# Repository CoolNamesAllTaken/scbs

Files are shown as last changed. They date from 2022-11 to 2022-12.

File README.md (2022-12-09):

# scbs
Single Cell Battery Simulator for testing a BMS.

# CELLSIM 4S

Cellsim 4S is a low-current battery pack simulator that simulates four battery cells in series. Each cell has a settable output voltage between 2.5-4.5V and a readable output current. Communication is done over a 9600 baud UART link using a custom serial protocol.

[DATASHEET](word/datasheet_cellsim_4s-1.0.0.pdf)

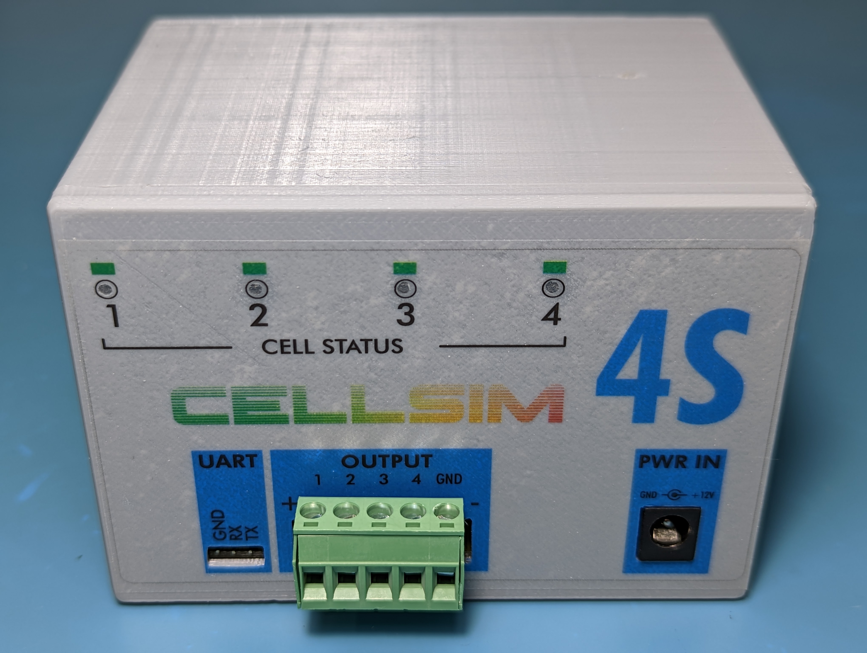
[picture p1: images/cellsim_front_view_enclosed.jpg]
Cellsim 4S Front View


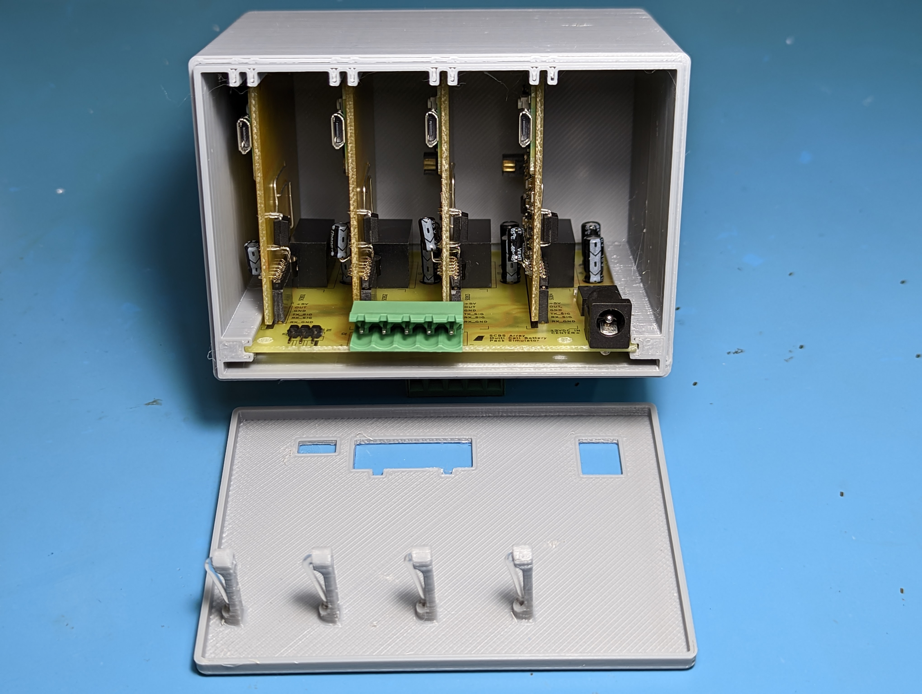
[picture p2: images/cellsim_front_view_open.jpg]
Cellsim 4S Internal View


# SCBS Pico

SCBS Pico is a single battery cell simulator that can be daisy chained with other devices of the same type in order to build a full simulated battery pack. It is the basic building block of the CELLSIM 4S.

[DATASHEET](word/datasheet_scbs_pico.pdf)

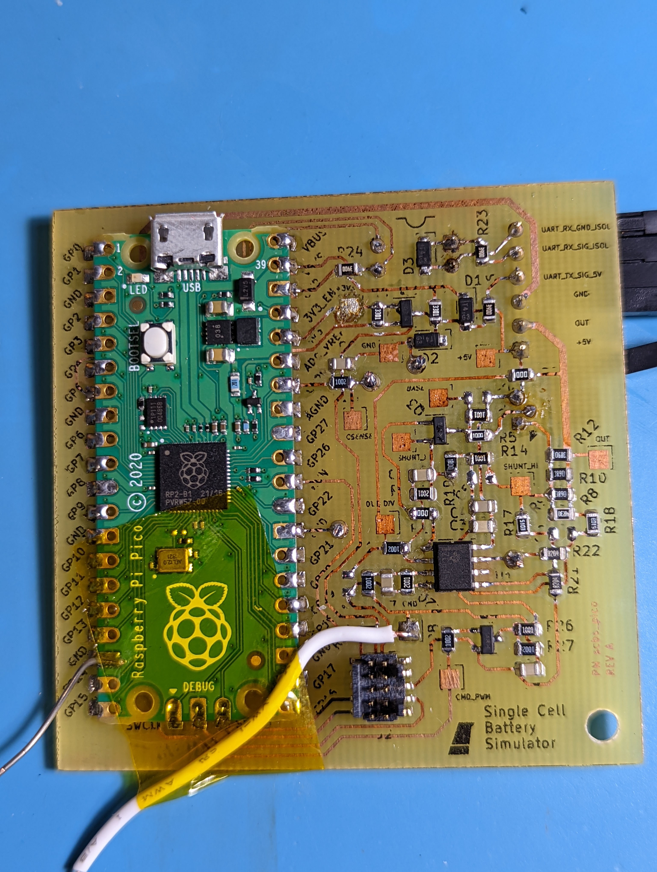
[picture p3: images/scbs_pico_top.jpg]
SCBS Pico Top


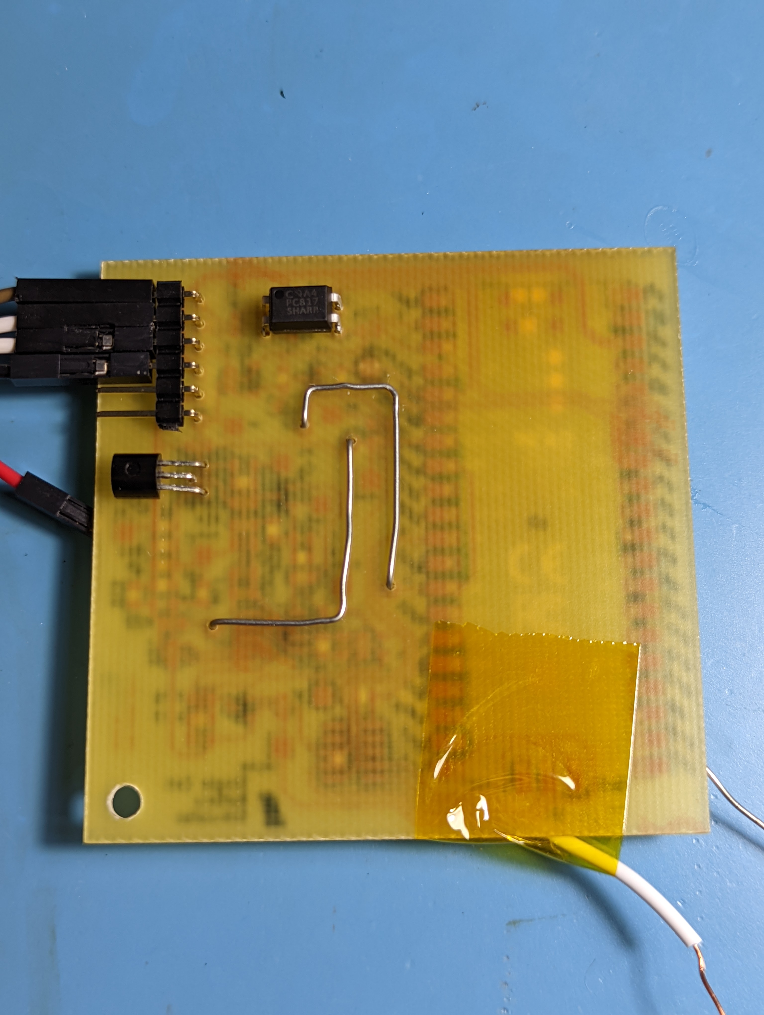
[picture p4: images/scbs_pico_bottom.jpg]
SCBS Pico Bottom


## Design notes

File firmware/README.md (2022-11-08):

# scbs

## Docker Setup Instructions

Run these commands from the top level directory.

NOTE: Cloning git repos onto windows may result in files with CR+LF line endings. Docker does NOT like these, and they will break everything. Make sure that you set `git config --global core.autocrlf false` before cloning repos that will get added or mounted to a Docker container.

### Build the Docker Image

Be sure to run `git submodule update --init` before building!

From this directory, run the following shell command.

```bash
docker build -t pico-dev-image .
```

### Run the Docker Container

Starting an interactive docker container on Linux or Mac. Mounts the `firmware` directory to `/root/firmware`.

```bash
docker run --name scbs-pico-dev-container -it --mount type=bind,source="$(pwd)",target=/root/scbs pico-dev-image
```

Starting an interactive docker container on Windows. Mounts the `firmware` directory to `/root/firmware`.

```bash
winpty docker run --name scbs-pico-dev-container -it --mount type=bind,source="$(pwd)",target=/root/scbs pico-dev-image
```

### Remove the Docker Image

```bash
docker image rm pico-dev-image
```

## Using VS Code inside the Docker Container

1. Install the Docker VS Code extension.
2. Right click on the available pico-dev-container and select "Attach Visual Studio Code" from the dropdown menu.
3. Open the attached VS Code, and wait for it to finish installing docker stuff.
4. In the attached visual studio code, install Cortex-Debug and the C/C++ extension.
5. To debug using the `launch.json` file in the `firmware/.vscode` directory, use the "Open Folder" function to navigate the attached VS Code instance to the `firmware` directory.

## Building Tests

### Build GoogleTest
In the docker container, navigate to the `modules/googletest` folder and execute the following.

```bash
cd googletest        # Main directory of the cloned repository.
mkdir build          # Create a directory to hold the build output.
cd build
cmake -DBUILD_SHARED_LIBS=ON .. # Generate build scripts with .so files.
make
```

This will generate the libgtest.so file that is a dependency of the SCBS tests in the next section.

### Build SCBS Tests
Create a folder called `test/build` and open a terminal there.
```bash
cmake ..
make
./scbs_test
```

## Initializing Submodules

From the `modules` directory, run `git submodule update --init --recursive`.

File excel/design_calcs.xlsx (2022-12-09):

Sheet: Design Calculations
Symbol | Value | Units | Note
Non-Inverting Amplifier Calculations (Control Circuit)
V_dac_max | 3.3 | V
V_batt_max | 4.7 | V | Add 0.2V of headroom to be safe.
R_fb | 10 | kOhms | Bottom feedback resistor (to GND) on opamp inverting input.
A_v_amp | 1.424242424
R_ft | 14.24142424 | kOhms
Compensation Network
R_comp | 10 | kOhms
C_comp | 10 | uF
f_c_comp | 1591.549431 | kHz | Corner frequency of filter on output of control op-amp.
PWM Smoothing Filter
R_fillt | 10000 | kOhms
C_filt | 10 | uF
f_c_filt | 1.591549431 | kHz
V_be_2n3904 | 0.7 | V
V_pwm_max | 3.3 | V
R_b_pwm | 10 | kOhms
I_b_pwm | 2.6
Current Sense Calculations
R_shunt | 0.9982142857 | Ohm
I_shunt_max | 200 | mA
V_shunt_max | 0.1996428571
V_sense_max | 3.3 | V
A_v | 16.52951699 | V_sense / V_shunt
Blob_A | 0.9429533626 | R_ub / (R_ub + R_ut)
R_ut | 510 | kOhms
R_ub | 8430.053667 | kOhms
R_db | 8430.053667 | kOhms
R_dt | 510 | kOhms

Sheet: Output Voltage Calibration
Set Voltage | Output Voltage | Offset |  | Estimated Offset
0 | 0.099 | 0.099 |  | 0.07958601399
0.5 | 0.423 | -0.077 |  | -0.04233473193
1 | 0.865 | -0.135 |  | -0.1331307692
1.5 | 1.314 | -0.186 |  | -0.1977706294
2 | 1.771 | -0.229 |  | -0.2412228438
2.5 | 2.237 | -0.263 |  | -0.2684559441
3 | 2.712 | -0.288 |  | -0.2844384615
3.5 | 3.196 | -0.304 |  | -0.2941389277
4 | 3.69 | -0.31 |  | -0.3025258741
4.5 | 4.194 | -0.306 |  | -0.3145678322
 |  |  | Offset Polynomial | COEFF_X^3 | COEFF_X^2 | COEFF_X | COEFF_CONST
 |  |  |  | -0.006624708625 | 0.07218648019 | -0.2782785548 | 0.07958601399

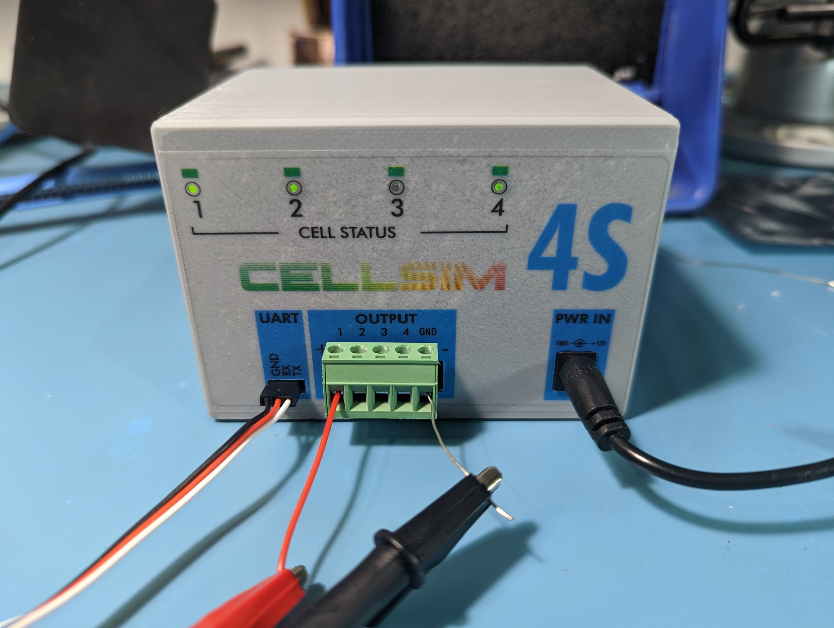
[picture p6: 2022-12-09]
images/cellsim_connected.jpg

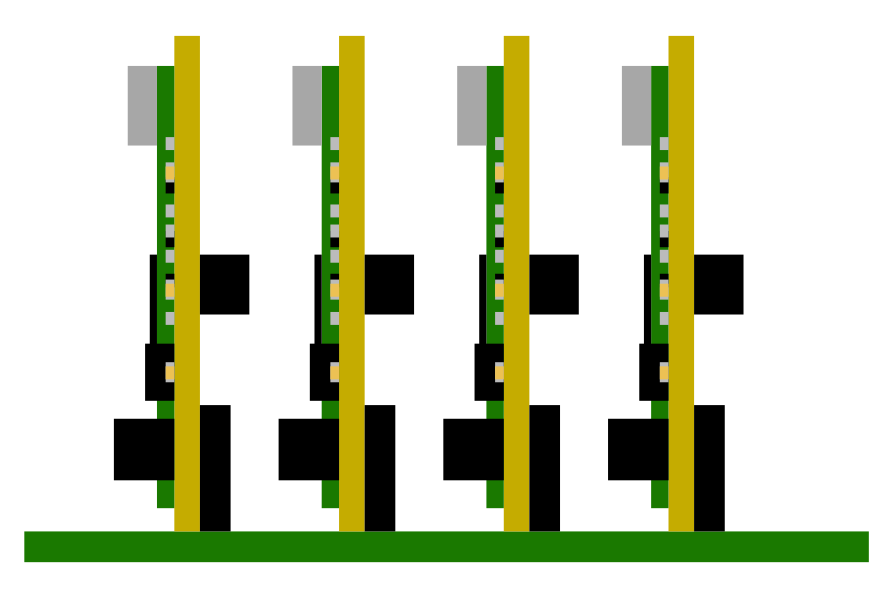
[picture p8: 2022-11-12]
affinity/exports/scbs_array.png

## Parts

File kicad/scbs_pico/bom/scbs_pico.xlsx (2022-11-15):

Source: | C:\git-checkouts\scbs\kicad\scbs_demo\scbs_demo.kicad_sch
Date: | 2022-11-10 20:58
Tool: | Eeschema (6.0.7)
Generator: | C:\Program Files\KiCad\6.0\bin\scripting\plugins/bom_csv_grouped_by_value.py
Component Count: | 62
Individual Components:
Item | Qty | Reference(s) | Value | LibPart | Footprint | Datasheet | MPN | REV | Standard Cost
 |  | C1 | 0.1uF | Device:C | Capacitor_SMD:C_0805_2012Metric | ~ |  |  | 0.1
 |  | C2 | DNP | Device:C | Capacitor_SMD:C_0805_2012Metric | ~ |  |  | 0.1
 |  | C3 | 1uF | Device:C | Capacitor_SMD:C_0805_2012Metric | ~ |  |  | 0.1
 |  | C4 | 0.1uF | Device:C | Capacitor_SMD:C_0805_2012Metric | ~ |  |  | 0.1
 |  | C5 | DNP | Device:C | Capacitor_SMD:C_0805_2012Metric | ~ |  |  | 0.1
 |  | C6 | DNP | Device:C | Capacitor_SMD:C_0805_2012Metric | ~ |  |  | 0.1
 |  | C7 | 0.1uF | Device:C | Capacitor_SMD:C_0805_2012Metric | ~ |  |  | 0.1
 |  | C8 | 0.1uF | Device:C | Capacitor_SMD:C_0805_2012Metric | ~ |  |  | 0.1
 |  | C9 | 0.1uF | Device:C | Capacitor_SMD:C_0805_2012Metric | ~ |  |  | 0.1
 |  | D1 | 1N4148 | Device:D | Diode_SMD:D_SOD-123 | ~ | 1N4148W-TP |  | 0.04
 |  | D2 | 1N4148 | Device:D | Diode_SMD:D_SOD-123 | ~ | 1N4148W-TP |  | 0.04
 |  | D3 | 1N4148 | Device:D | Diode_SMD:D_SOD-123 | ~ | 1N4148W-TP |  | 0.04
 |  | J1 | Conn_01x06_Male | Connector:Conn_01x06_Male | Connector_PinHeader_2.54mm:PinHeader_1x06_P2.54mm_Horizontal | ~ | PREC006SBAN-M71RC |  | 0.1
 |  | J2 | Conn_ARM_JTAG_SWD_10 | Connector:Conn_ARM_JTAG_SWD_10 | Connector_PinHeader_1.27mm:PinHeader_2x05_P1.27mm_Vertical_SMD | http://infocenter.arm.com/help/topic/com.arm.doc.ddi0314h/DDI0314H_coresight_components_trm.pdf | 4048 |  | 1.95
 |  | PCB1 | PCB | Custom_Placeholder:PCB | Custom_Graphic:PCB_PN_REV_small |  | PN scbs_pico | REV A | 0
 |  | Q1 | 2N2907 | Device:Q_PNP_CBE | Package_TO_SOT_THT:TO-92 | https://www.onsemi.com/pdf/datasheet/p2n2907a-d.pdf | PN2907ATF |  | 0.07
 |  | Q2 | 2N7002 | Transistor_FET:2N7002 | Package_TO_SOT_SMD:SOT-23 | https://www.onsemi.com/pub/Collateral/NDS7002A-D.PDF | 2N7002 |  | 0.07
 |  | Q3 | MMBT3904 | Transistor_BJT:MMBT3904 | Package_TO_SOT_SMD:SOT-23 | https://www.onsemi.com/pub/Collateral/2N3903-D.PDF |  |  | 0.04
 |  | Q4 | MMBT3904 | Transistor_BJT:MMBT3904 | Package_TO_SOT_SMD:SOT-23 | https://www.onsemi.com/pub/Collateral/2N3903-D.PDF |  |  | 0.04
 |  | R1 | 2k | Device:R_US | Resistor_SMD:R_0805_2012Metric | ~ |  |  | 0.01
 |  | R2 | 1k | Device:R_US | Resistor_SMD:R_0805_2012Metric | ~ |  |  | 0.01
 |  | R3 | 3k3 | Device:R_US | Resistor_SMD:R_0805_2012Metric | ~ |  |  | 0.01
 |  | R4 | 3k3 | Device:R_US | Resistor_SMD:R_0805_2012Metric | ~ |  |  | 0.01
 |  | R5 | 100R | Device:R_US | Resistor_SMD:R_0805_2012Metric | ~ |  |  | 0.01
 |  | R6 | 390R | Device:R_US | Resistor_SMD:R_0805_2012Metric | ~ |  |  | 0.01
 |  | R7 | 0R | Device:R_US | Resistor_SMD:R_0805_2012Metric | ~ |  |  | 0.01
 |  | R8 | 4R 1% 0805 | Device:R_US | Resistor_SMD:R_0805_2012Metric | ~ |  |  | 0.01
 |  | R9 | 4R 1% 0805 | Device:R_US | Resistor_SMD:R_0805_2012Metric | ~ |  |  | 0.01
 |  | R10 | 4R 1% 0805 | Device:R_US | Resistor_SMD:R_0805_2012Metric | ~ |  |  | 0.01
 |  | R11 | 10k | Device:R_US | Resistor_SMD:R_0805_2012Metric | ~ |  |  | 0.01
 |  | R12 | 4R 1% 0805 | Device:R_US | Resistor_SMD:R_0805_2012Metric | ~ |  |  | 0.01
 |  | R13 | 0R | Device:R_US | Resistor_SMD:R_0805_2012Metric | ~ |  |  | 0.01
 |  | R14 | 1k | Device:R_US | Resistor_SMD:R_0805_2012Metric | ~ |  |  | 0.01
 |  | R15 | 10k | Device:R_US | Resistor_SMD:R_0805_2012Metric | ~ |  |  | 0.01
 |  | R16 | DNP | Device:R_US | Resistor_SMD:R_0805_2012Metric | ~ |  |  | 0.01
 |  | R17 | 500k 0.1% | Device:R_US | Resistor_SMD:R_0805_2012Metric | ~ |  |  | 0.01
 |  | R18 | 500k 0.1% | Device:R_US | Resistor_SMD:R_0805_2012Metric | ~ |  |  | 0.01
 |  | R19 | 1R | Device:R_US | Resistor_SMD:R_0805_2012Metric | ~ |  |  | 0.01
 |  | R20 | 2k | Device:R_US | Resistor_SMD:R_0805_2012Metric | ~ |  |  | 0.01
 |  | R21 | 8.25M 0.1% | Device:R_US | Resistor_SMD:R_0805_2012Metric | ~ |  |  | 0.01
 |  | R22 | 8.25M 0.1% | Device:R_US | Resistor_SMD:R_0805_2012Metric | ~ |  |  | 0.01
 |  | R23 | 390R | Device:R_US | Resistor_SMD:R_0805_2012Metric | ~ |  |  | 0.01
 |  | R24 | 390R | Device:R_US | Resistor_SMD:R_0805_2012Metric | ~ |  |  | 0.01
 |  | R25 | 10k | Device:R_US | Resistor_SMD:R_0805_2012Metric | ~ |  |  | 0.01
 |  | R26 | 1k | Device:R_US | Resistor_SMD:R_0805_2012Metric | ~ |  |  | 0.01
 |  | R27 | 10k | Device:R_US | Resistor_SMD:R_0805_2012Metric | ~ |  |  | 0.01
 |  | R28 | 10k | Device:R_US | Resistor_SMD:R_0805_2012Metric | ~ |  |  | 0.01
 |  | R30 | 10k | Device:R_US | Resistor_SMD:R_0805_2012Metric | ~ |  |  | 0.01
 |  | TP1 | TestPoint | Connector:TestPoint | TestPoint:TestPoint_Pad_2.0x2.0mm | ~ |  |  | 0
 |  | TP2 | TestPoint | Connector:TestPoint | TestPoint:TestPoint_Pad_2.0x2.0mm | ~ |  |  | 0
 |  | TP3 | TestPoint | Connector:TestPoint | TestPoint:TestPoint_Pad_2.0x2.0mm | ~ |  |  | 0
 |  | TP4 | TestPoint | Connector:TestPoint | TestPoint:TestPoint_Pad_2.0x2.0mm | ~ |  |  | 0
 |  | TP5 | TestPoint | Connector:TestPoint | TestPoint:TestPoint_Pad_2.0x2.0mm | ~ |  |  | 0
 |  | TP6 | TestPoint | Connector:TestPoint | TestPoint:TestPoint_Pad_2.0x2.0mm | ~ |  |  | 0
 |  | TP7 | TestPoint | Connector:TestPoint | TestPoint:TestPoint_Pad_2.0x2.0mm | ~ |  |  | 0
 |  | TP8 | TestPoint | Connector:TestPoint | TestPoint:TestPoint_Pad_2.0x2.0mm | ~ |  |  | 0
 |  | TP9 | TestPoint | Connector:TestPoint | TestPoint:TestPoint_Pad_2.0x2.0mm | ~ |  |  | 0
 |  | TP10 | TestPoint | Connector:TestPoint | TestPoint:TestPoint_Pad_2.0x2.0mm | ~ |  |  | 0
 |  | TP11 | TestPoint | Connector:TestPoint | TestPoint:TestPoint_Pad_2.0x2.0mm | ~ |  |  | 0
 |  | U1 | TLV9062xD | Amplifier_Operational:TLV9062xD | Package_SO:SOIC-8_3.9x4.9mm_P1.27mm | https://www.ti.com/lit/ds/symlink/tlv9062.pdf | TLV9062IDR |  | 0.44
 |  | U2 | PC817 | Isolator:PC817 | Package_DIP:DIP-4_W7.62mm | http://www.soselectronic.cz/a_info/resource/d/pc817.pdf | BPC-817S ( C BIN ) |  | 0.15
 |  | U3 | Pico | Custom_MCU:Pico | Custom_Module:RPi_Pico_SMD_TH | https://datasheets.raspberrypi.com/pico/pico-datasheet.pdf | SC0915 |  | 4
Collated Components:
Item | Qty | Reference(s) | Value | LibPart | Footprint | Datasheet | MPN | REV | Standard Cost | Subtotal
1 | 5 | C1, C4, C7, C8, C9 | 0.1uF | Device:C | Capacitor_SMD:C_0805_2012Metric | ~ |  |  | 0.1 | 0.5
2 | 3 | C2, C5, C6 | DNP | Device:C | Capacitor_SMD:C_0805_2012Metric | ~ |  |  | 0.1 | 0.3
3 | 1 | C3 | 1uF | Device:C | Capacitor_SMD:C_0805_2012Metric | ~ |  |  | 0.1 | 0.1
4 | 3 | D1, D2, D3 | 1N4148 | Device:D | Diode_SMD:D_SOD-123 | ~ | 1N4148W-TP |  | 0.04 | 0.12
5 | 1 | J1 | Conn_01x06_Male | Connector:Conn_01x06_Male | Connector_PinHeader_2.54mm:PinHeader_1x06_P2.54mm_Horizontal | ~ | PREC006SBAN-M71RC |  | 0.1 | 0.1
6 | 1 | J2 | Conn_ARM_JTAG_SWD_10 | Connector:Conn_ARM_JTAG_SWD_10 | Connector_PinHeader_1.27mm:PinHeader_2x05_P1.27mm_Vertical_SMD | http://infocenter.arm.com/help/topic/com.arm.doc.ddi0314h/DDI0314H_coresight_components_trm.pdf | 4048 |  | 1.95 | 1.95
7 | 1 | PCB1 | PCB | Custom_Placeholder:PCB | Custom_Graphic:PCB_PN_REV_small |  | PN scbs_pico | REV A | 0 | 0
8 | 1 | Q1 | 2N2907 | Device:Q_PNP_CBE | Package_TO_SOT_THT:TO-92 | https://www.onsemi.com/pdf/datasheet/p2n2907a-d.pdf | PN2907ATF |  | 0.07 | 0.07
9 | 1 | Q2 | 2N7002 | Transistor_FET:2N7002 | Package_TO_SOT_SMD:SOT-23 | https://www.onsemi.com/pub/Collateral/NDS7002A-D.PDF | 2N7002 |  | 0.07 | 0.07
10 | 2 | Q3, Q4 | MMBT3904 | Transistor_BJT:MMBT3904 | Package_TO_SOT_SMD:SOT-23 | https://www.onsemi.com/pub/Collateral/2N3903-D.PDF |  |  | 0.04 | 0.08
11 | 2 | R1, R20 | 2k | Device:R_US | Resistor_SMD:R_0805_2012Metric | ~ |  |  | 0.01 | 0.02
12 | 3 | R2, R14, R26 | 1k | Device:R_US | Resistor_SMD:R_0805_2012Metric | ~ |  |  | 0.01 | 0.03
13 | 2 | R3, R4 | 3k3 | Device:R_US | Resistor_SMD:R_0805_2012Metric | ~ |  |  | 0.01 | 0.02
14 | 1 | R5 | 100R | Device:R_US | Resistor_SMD:R_0805_2012Metric | ~ |  |  | 0.01 | 0.01
15 | 3 | R6, R23, R24 | 390R | Device:R_US | Resistor_SMD:R_0805_2012Metric | ~ |  |  | 0.01 | 0.03
16 | 2 | R7, R13 | 0R | Device:R_US | Resistor_SMD:R_0805_2012Metric | ~ |  |  | 0.01 | 0.02
17 | 4 | R8, R9, R10, R12 | 4R 1% 0805 | Device:R_US | Resistor_SMD:R_0805_2012Metric | ~ |  |  | 0.01 | 0.04
18 | 6 | R11, R15, R25, R27, R28, R30 | 10k | Device:R_US | Resistor_SMD:R_0805_2012Metric | ~ |  |  | 0.01 | 0.06
19 | 1 | R16 | DNP | Device:R_US | Resistor_SMD:R_0805_2012Metric | ~ |  |  | 0.01 | 0.01
20 | 2 | R17, R18 | 500k 0.1% | Device:R_US | Resistor_SMD:R_0805_2012Metric | ~ |  |  | 0.01 | 0.02
21 | 1 | R19 | 1R | Device:R_US | Resistor_SMD:R_0805_2012Metric | ~ |  |  | 0.01 | 0.01
22 | 2 | R21, R22 | 8.25M 0.1% | Device:R_US | Resistor_SMD:R_0805_2012Metric | ~ |  |  | 0.01 | 0.02
23 | 11 | TP1, TP2, TP3, TP4, TP5, TP6, TP7, TP8, TP9, TP10, TP11 | TestPoint | Connector:TestPoint | TestPoint:TestPoint_Pad_2.0x2.0mm | ~ |  |  | 0 | 0
24 | 1 | U1 | TLV9062xD | Amplifier_Operational:TLV9062xD | Package_SO:SOIC-8_3.9x4.9mm_P1.27mm | https://www.ti.com/lit/ds/symlink/tlv9062.pdf | TLV9062IDR |  | 0.44 | 0.44
25 | 1 | U2 | PC817 | Isolator:PC817 | Package_DIP:DIP-4_W7.62mm | http://www.soselectronic.cz/a_info/resource/d/pc817.pdf | BPC-817S ( C BIN ) |  | 0.15 | 0.15
26 | 1 | U3 | Pico | Custom_MCU:Pico | Custom_Module:RPi_Pico_SMD_TH | https://datasheets.raspberrypi.com/pico/pico-datasheet.pdf | SC0915 |  | 4 | 4
 |  |  |  |  |  |  |  |  | Unit Cost | 8.17

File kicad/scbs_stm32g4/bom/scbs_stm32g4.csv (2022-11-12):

Source: | C:\git-checkouts\scbs\kicad\scbs_demo\scbs_demo.kicad_sch
Date: | 11/10/2022 8:58:13 PM
Tool: | Eeschema (6.0.7)
Generator: | C:\Program Files\KiCad\6.0\bin\scripting\plugins/bom_csv_grouped_by_value.py
Component Count: | 62
Individual Components:
Item | Qty | Reference(s) | Value | LibPart | Footprint | Datasheet | MPN | REV | Standard Cost
 |  | C1 | 0.1uF | Device:C | Capacitor_SMD:C_0805_2012Metric | ~ |  |  | 0.10
 |  | C2 | DNP | Device:C | Capacitor_SMD:C_0805_2012Metric | ~ |  |  | 0.10
 |  | C3 | 1uF | Device:C | Capacitor_SMD:C_0805_2012Metric | ~ |  |  | 0.10
 |  | C4 | 0.1uF | Device:C | Capacitor_SMD:C_0805_2012Metric | ~ |  |  | 0.10
 |  | C5 | DNP | Device:C | Capacitor_SMD:C_0805_2012Metric | ~ |  |  | 0.10
 |  | C6 | DNP | Device:C | Capacitor_SMD:C_0805_2012Metric | ~ |  |  | 0.10
 |  | C7 | 0.1uF | Device:C | Capacitor_SMD:C_0805_2012Metric | ~ |  |  | 0.10
 |  | C8 | 0.1uF | Device:C | Capacitor_SMD:C_0805_2012Metric | ~ |  |  | 0.10
 |  | C9 | 0.1uF | Device:C | Capacitor_SMD:C_0805_2012Metric | ~ |  |  | 0.10
 |  | D1 | 1N4148 | Device:D | Diode_SMD:D_SOD-123 | ~ | 1N4148W-TP |  | 0.04
 |  | D2 | 1N4148 | Device:D | Diode_SMD:D_SOD-123 | ~ | 1N4148W-TP |  | 0.04
 |  | D3 | 1N4148 | Device:D | Diode_SMD:D_SOD-123 | ~ | 1N4148W-TP |  | 0.04
 |  | J1 | Conn_01x06_Male | Connector:Conn_01x06_Male | Connector_PinHeader_2.54mm:PinHeader_1x06_P2.54mm_Horizontal | ~ | PREC006SBAN-M71RC |  | 0.10
 |  | J2 | Conn_ARM_JTAG_SWD_10 | Connector:Conn_ARM_JTAG_SWD_10 | Connector_PinHeader_1.27mm:PinHeader_2x05_P1.27mm_Vertical_SMD | http://infocenter.arm.com/help/topic/com.arm.doc.ddi0314h/DDI0314H_coresight_components_trm.pdf | 4048 |  | 1.95
 |  | PCB1 | PCB | Custom_Placeholder:PCB | Custom_Graphic:PCB_PN_REV_small |  | PN scbs_pico | REV A | 0.00
 |  | Q1 | 2N2907 | Device:Q_PNP_CBE | Package_TO_SOT_THT:TO-92 | https://www.onsemi.com/pdf/datasheet/p2n2907a-d.pdf | PN2907ATF |  | 0.07
 |  | Q2 | 2N7002 | Transistor_FET:2N7002 | Package_TO_SOT_SMD:SOT-23 | https://www.onsemi.com/pub/Collateral/NDS7002A-D.PDF | 2N7002 |  | 0.07
 |  | Q3 | MMBT3904 | Transistor_BJT:MMBT3904 | Package_TO_SOT_SMD:SOT-23 | https://www.onsemi.com/pub/Collateral/2N3903-D.PDF |  |  | 0.04
 |  | Q4 | MMBT3904 | Transistor_BJT:MMBT3904 | Package_TO_SOT_SMD:SOT-23 | https://www.onsemi.com/pub/Collateral/2N3903-D.PDF |  |  | 0.04
 |  | R1 | 2k | Device:R_US | Resistor_SMD:R_0805_2012Metric | ~ |  |  | 0.01
 |  | R2 | 1k | Device:R_US | Resistor_SMD:R_0805_2012Metric | ~ |  |  | 0.01
 |  | R3 | 3k3 | Device:R_US | Resistor_SMD:R_0805_2012Metric | ~ |  |  | 0.01
 |  | R4 | 3k3 | Device:R_US | Resistor_SMD:R_0805_2012Metric | ~ |  |  | 0.01
 |  | R5 | 100R | Device:R_US | Resistor_SMD:R_0805_2012Metric | ~ |  |  | 0.01
 |  | R6 | 390R | Device:R_US | Resistor_SMD:R_0805_2012Metric | ~ |  |  | 0.01
 |  | R7 | 0R | Device:R_US | Resistor_SMD:R_0805_2012Metric | ~ |  |  | 0.01
 |  | R8 | 4R 1% 0805 | Device:R_US | Resistor_SMD:R_0805_2012Metric | ~ |  |  | 0.01
 |  | R9 | 4R 1% 0805 | Device:R_US | Resistor_SMD:R_0805_2012Metric | ~ |  |  | 0.01
 |  | R10 | 4R 1% 0805 | Device:R_US | Resistor_SMD:R_0805_2012Metric | ~ |  |  | 0.01
 |  | R11 | 10k | Device:R_US | Resistor_SMD:R_0805_2012Metric | ~ |  |  | 0.01
 |  | R12 | 4R 1% 0805 | Device:R_US | Resistor_SMD:R_0805_2012Metric | ~ |  |  | 0.01
 |  | R13 | 0R | Device:R_US | Resistor_SMD:R_0805_2012Metric | ~ |  |  | 0.01
 |  | R14 | 1k | Device:R_US | Resistor_SMD:R_0805_2012Metric | ~ |  |  | 0.01
 |  | R15 | 10k | Device:R_US | Resistor_SMD:R_0805_2012Metric | ~ |  |  | 0.01
 |  | R16 | DNP | Device:R_US | Resistor_SMD:R_0805_2012Metric | ~ |  |  | 0.01
 |  | R17 | 500k 0.1% | Device:R_US | Resistor_SMD:R_0805_2012Metric | ~ |  |  | 0.01
 |  | R18 | 500k 0.1% | Device:R_US | Resistor_SMD:R_0805_2012Metric | ~ |  |  | 0.01
 |  | R19 | 1R | Device:R_US | Resistor_SMD:R_0805_2012Metric | ~ |  |  | 0.01
 |  | R20 | 2k | Device:R_US | Resistor_SMD:R_0805_2012Metric | ~ |  |  | 0.01
 |  | R21 | 8.25M 0.1% | Device:R_US | Resistor_SMD:R_0805_2012Metric | ~ |  |  | 0.01
 |  | R22 | 8.25M 0.1% | Device:R_US | Resistor_SMD:R_0805_2012Metric | ~ |  |  | 0.01
 |  | R23 | 390R | Device:R_US | Resistor_SMD:R_0805_2012Metric | ~ |  |  | 0.01
 |  | R24 | 390R | Device:R_US | Resistor_SMD:R_0805_2012Metric | ~ |  |  | 0.01
 |  | R25 | 10k | Device:R_US | Resistor_SMD:R_0805_2012Metric | ~ |  |  | 0.01
 |  | R26 | 1k | Device:R_US | Resistor_SMD:R_0805_2012Metric | ~ |  |  | 0.01
 |  | R27 | 10k | Device:R_US | Resistor_SMD:R_0805_2012Metric | ~ |  |  | 0.01
 |  | R28 | 10k | Device:R_US | Resistor_SMD:R_0805_2012Metric | ~ |  |  | 0.01
 |  | R30 | 10k | Device:R_US | Resistor_SMD:R_0805_2012Metric | ~ |  |  | 0.01
 |  | TP1 | TestPoint | Connector:TestPoint | TestPoint:TestPoint_Pad_2.0x2.0mm | ~ |  |  | 0.00
 |  | TP2 | TestPoint | Connector:TestPoint | TestPoint:TestPoint_Pad_2.0x2.0mm | ~ |  |  | 0.00
 |  | TP3 | TestPoint | Connector:TestPoint | TestPoint:TestPoint_Pad_2.0x2.0mm | ~ |  |  | 0.00
 |  | TP4 | TestPoint | Connector:TestPoint | TestPoint:TestPoint_Pad_2.0x2.0mm | ~ |  |  | 0.00
 |  | TP5 | TestPoint | Connector:TestPoint | TestPoint:TestPoint_Pad_2.0x2.0mm | ~ |  |  | 0.00
 |  | TP6 | TestPoint | Connector:TestPoint | TestPoint:TestPoint_Pad_2.0x2.0mm | ~ |  |  | 0.00
 |  | TP7 | TestPoint | Connector:TestPoint | TestPoint:TestPoint_Pad_2.0x2.0mm | ~ |  |  | 0.00
 |  | TP8 | TestPoint | Connector:TestPoint | TestPoint:TestPoint_Pad_2.0x2.0mm | ~ |  |  | 0.00
 |  | TP9 | TestPoint | Connector:TestPoint | TestPoint:TestPoint_Pad_2.0x2.0mm | ~ |  |  | 0.00
 |  | TP10 | TestPoint | Connector:TestPoint | TestPoint:TestPoint_Pad_2.0x2.0mm | ~ |  |  | 0.00
 |  | TP11 | TestPoint | Connector:TestPoint | TestPoint:TestPoint_Pad_2.0x2.0mm | ~ |  |  | 0.00
 |  | U1 | TLV9062xD | Amplifier_Operational:TLV9062xD | Package_SO:SOIC-8_3.9x4.9mm_P1.27mm | https://www.ti.com/lit/ds/symlink/tlv9062.pdf | TLV9062IDR |  | 0.44
 |  | U2 | PC817 | Isolator:PC817 | Package_DIP:DIP-4_W7.62mm | http://www.soselectronic.cz/a_info/resource/d/pc817.pdf | BPC-817S ( C BIN ) |  | 0.15
 |  | U3 | Pico | Custom_MCU:Pico | Custom_Module:RPi_Pico_SMD_TH | https://datasheets.raspberrypi.com/pico/pico-datasheet.pdf | SC0915 |  | 4.00
Collated Components:
Item | Qty | Reference(s) | Value | LibPart | Footprint | Datasheet | MPN | REV | Standard Cost
1 | 5 | C1, C4, C7, C8, C9 | 0.1uF | Device:C | Capacitor_SMD:C_0805_2012Metric | ~ |  |  | 0.10
2 | 3 | C2, C5, C6 | DNP | Device:C | Capacitor_SMD:C_0805_2012Metric | ~ |  |  | 0.10
3 | 1 | C3 | 1uF | Device:C | Capacitor_SMD:C_0805_2012Metric | ~ |  |  | 0.10
4 | 3 | D1, D2, D3 | 1N4148 | Device:D | Diode_SMD:D_SOD-123 | ~ | 1N4148W-TP |  | 0.04
5 | 1 | J1 | Conn_01x06_Male | Connector:Conn_01x06_Male | Connector_PinHeader_2.54mm:PinHeader_1x06_P2.54mm_Horizontal | ~ | PREC006SBAN-M71RC |  | 0.10
6 | 1 | J2 | Conn_ARM_JTAG_SWD_10 | Connector:Conn_ARM_JTAG_SWD_10 | Connector_PinHeader_1.27mm:PinHeader_2x05_P1.27mm_Vertical_SMD | http://infocenter.arm.com/help/topic/com.arm.doc.ddi0314h/DDI0314H_coresight_components_trm.pdf | 4048 |  | 1.95
7 | 1 | PCB1 | PCB | Custom_Placeholder:PCB | Custom_Graphic:PCB_PN_REV_small |  | PN scbs_pico | REV A | 0.00
8 | 1 | Q1 | 2N2907 | Device:Q_PNP_CBE | Package_TO_SOT_THT:TO-92 | https://www.onsemi.com/pdf/datasheet/p2n2907a-d.pdf | PN2907ATF |  | 0.07
9 | 1 | Q2 | 2N7002 | Transistor_FET:2N7002 | Package_TO_SOT_SMD:SOT-23 | https://www.onsemi.com/pub/Collateral/NDS7002A-D.PDF | 2N7002 |  | 0.07
10 | 2 | Q3, Q4 | MMBT3904 | Transistor_BJT:MMBT3904 | Package_TO_SOT_SMD:SOT-23 | https://www.onsemi.com/pub/Collateral/2N3903-D.PDF |  |  | 0.04
11 | 2 | R1, R20 | 2k | Device:R_US | Resistor_SMD:R_0805_2012Metric | ~ |  |  | 0.01
12 | 3 | R2, R14, R26 | 1k | Device:R_US | Resistor_SMD:R_0805_2012Metric | ~ |  |  | 0.01
13 | 2 | R3, R4 | 3k3 | Device:R_US | Resistor_SMD:R_0805_2012Metric | ~ |  |  | 0.01
14 | 1 | R5 | 100R | Device:R_US | Resistor_SMD:R_0805_2012Metric | ~ |  |  | 0.01
15 | 3 | R6, R23, R24 | 390R | Device:R_US | Resistor_SMD:R_0805_2012Metric | ~ |  |  | 0.01
16 | 2 | R7, R13 | 0R | Device:R_US | Resistor_SMD:R_0805_2012Metric | ~ |  |  | 0.01
17 | 4 | R8, R9, R10, R12 | 4R 1% 0805 | Device:R_US | Resistor_SMD:R_0805_2012Metric | ~ |  |  | 0.01
18 | 6 | R11, R15, R25, R27, R28, R30 | 10k | Device:R_US | Resistor_SMD:R_0805_2012Metric | ~ |  |  | 0.01
19 | 1 | R16 | DNP | Device:R_US | Resistor_SMD:R_0805_2012Metric | ~ |  |  | 0.01
20 | 2 | R17, R18 | 500k 0.1% | Device:R_US | Resistor_SMD:R_0805_2012Metric | ~ |  |  | 0.01
21 | 1 | R19 | 1R | Device:R_US | Resistor_SMD:R_0805_2012Metric | ~ |  |  | 0.01
22 | 2 | R21, R22 | 8.25M 0.1% | Device:R_US | Resistor_SMD:R_0805_2012Metric | ~ |  |  | 0.01
23 | 11 | TP1, TP2, TP3, TP4, TP5, TP6, TP7, TP8, TP9, TP10, TP11 | TestPoint | Connector:TestPoint | TestPoint:TestPoint_Pad_2.0x2.0mm | ~ |  |  | 0.00
24 | 1 | U1 | TLV9062xD | Amplifier_Operational:TLV9062xD | Package_SO:SOIC-8_3.9x4.9mm_P1.27mm | https://www.ti.com/lit/ds/symlink/tlv9062.pdf | TLV9062IDR |  | 0.44
25 | 1 | U2 | PC817 | Isolator:PC817 | Package_DIP:DIP-4_W7.62mm | http://www.soselectronic.cz/a_info/resource/d/pc817.pdf | BPC-817S ( C BIN ) |  | 0.15
26 | 1 | U3 | Pico | Custom_MCU:Pico | Custom_Module:RPi_Pico_SMD_TH | https://datasheets.raspberrypi.com/pico/pico-datasheet.pdf | SC0915 |  | 4.00

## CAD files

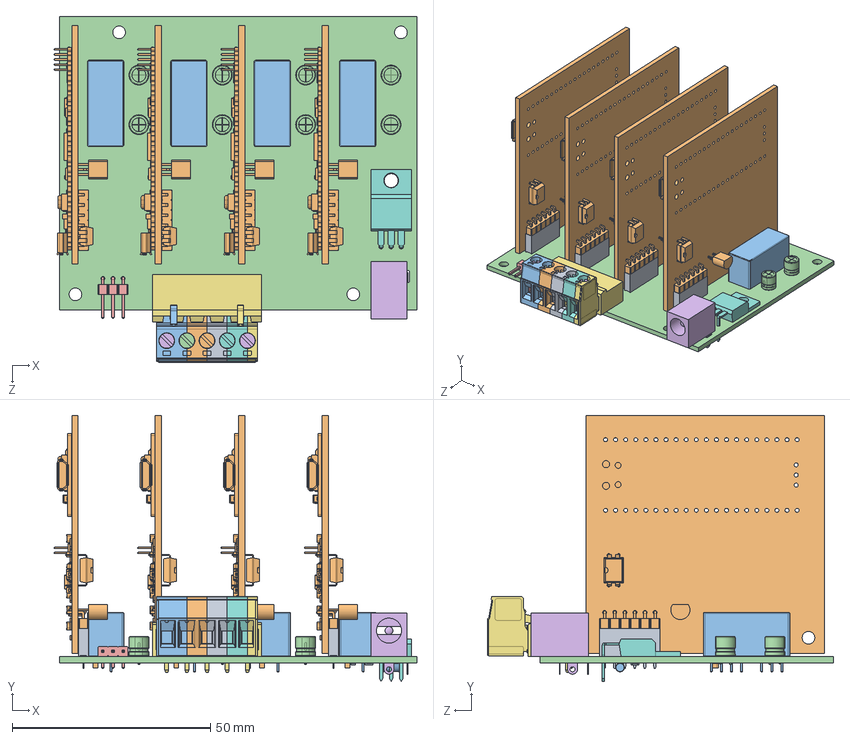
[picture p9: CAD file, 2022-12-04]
solidworks/scbs_array_enclosed_assy.SLDASM
91.3 x 67.0 x 87.2 mm
scbs_array PCB

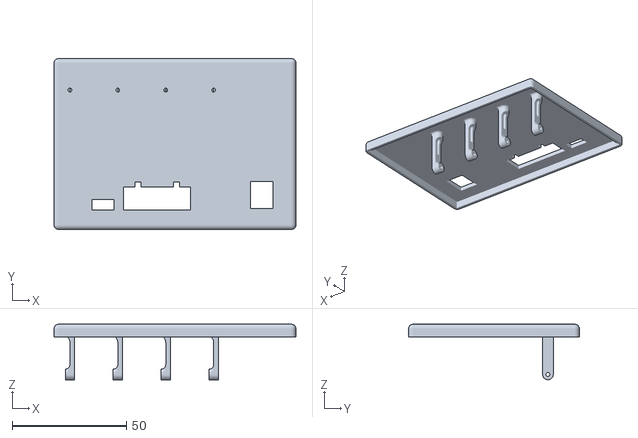
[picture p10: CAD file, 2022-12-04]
solidworks/fab/enclosure_front_panel.STL
106.0 x 74.8 x 24.3

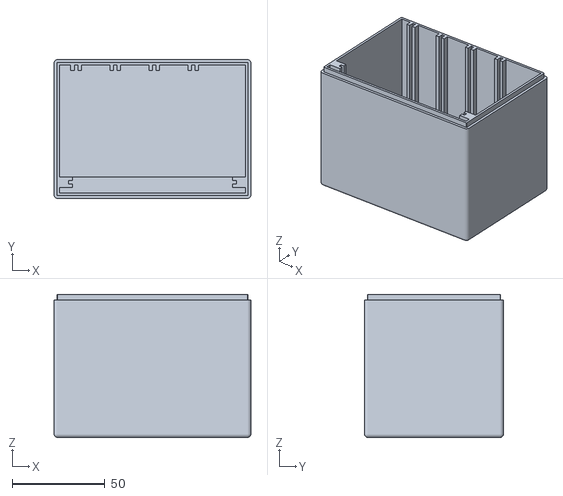
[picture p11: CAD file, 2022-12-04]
solidworks/fab/enclosure_back_shell.STL
106.0 x 74.8 x 77.0

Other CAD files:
solidworks/scbs_array/SOFNG_DC005-T20.SLDASM
solidworks/scbs_array/PinSocket_1x06_P2.54mm_Vertical.SLDASM
solidworks/scbs_array/PinHeader_1x03_P2.54mm_Horizontal.SLDASM
solidworks/scbs_array/D_MELF.SLDASM
solidworks/scbs_array/R_0805_2012Metric.SLDASM
solidworks/scbs_array/CP_Radial_D5.0mm_P2.50mm.SLDASM
solidworks/scbs_array/TO-220-3_Horizontal_TabDown.SLDASM
solidworks/scbs_array/PhoenixContact_MSTBA_2,5_5-G-5,08_1x05_P5.08mm_Horizontal.SLDASM
solidworks/scbs_array/C_0805_2012Metric.SLDASM
solidworks/scbs_array/pxc_1757048_06_MSTB-2-5-5-ST-5-08_3D.SLDASM
solidworks/scbs_array/scbs_array_pcba.SLDASM
solidworks/scbs_array/scbs_pico.SLDASM
solidworks/scbs_array/Converter_DCDC_TRACO_TMR-xxxx_THT.SLDASM
solidworks/scbs_array/SOLID-4.SLDPRT
solidworks/scbs_array/SOLID-0.SLDPRT
solidworks/fab/enclosure_parts.3mf
solidworks/scbs_array/2022_06_08_09_32_02_0611.SLDPRT
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

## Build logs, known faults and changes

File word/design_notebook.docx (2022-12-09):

# Design Specs

Power Supply: Isolated 5VDC

Balance Current: 200mA max (out of the cell simulator)

Output Voltage: 2.5-4.5V +/- 5%

Balance Current can be measured with tolerance of +/-10%

Microcontroller: STM32G431CBT6

UART interface for RX / TX.

# Initial Ideas

## Linear Regulator Based Circuit

Idea: use a 1117 series linear regulator as the output regulator and output stage, since it can source high current (up to 1A). Use an ADJ variant and control the feedback pin with an op-amp in order to set the output voltage. Add current sense in the output path, but close the loop around the output of the current sense resistor in order to avoid an offset voltage on the output when current is being drawn.

Scrapped because not enough headroom. 1117 requires >1V of headroom and cell simulator needs to output up to 4.5V with a 5V supply. Don’t want to deal with adding a boost converter etc.

## Lots of Op-Amps in Parallel

Idea: use a number of op-amps in parallel as the control and output stage.

Scrapped because would need to current sense after the closed loop, (induces an offset voltage on the output), or only current sense one op-amp channel and assume that all op-amps are sourcing the same current.

## Get a Big Op Amp and Call It a Day

Idea: just get a big op-amp that can source 200mA.

Not very fun. Also don’t have any lying around, and higher current op-amps tend to have worse characteristics for input offset voltage / bias current / etc.

## Op Amp with Discrete BJT +Rail Output Stage

Idea: beef up an op-amp’s output stage with discrete BJT’s in a manner that allows the output to get as close to the +5V rail as possible. Close the loop around a set of current sense resistors on the high side of the output.

Haven’t found anything wrong with this yet!

# Design Iterations

## Demo Board Rev 0.1

### Design Overview

Was hoping to use LM358’s since neither op-amp needs a rail-to-rail output, but got snagged on the fact that I needed a rail-to-rail input. The input of the control op-amp was clipping and preventing the output stage from being properly commanded to a high enough output voltage.

Encountered lots of issues with stability in simulation until I added a compensator network on the output of the control op-amp. Needed to roll off the open-loop gain before the phase got to 0°. Practically the issue with stability / oscillation can be seen when the output voltage gets really close to the commanded voltage; the output of the op-amp goes nuts and swings high/low pretty aggressively. Knocking this down with a filter prevents this oscillation from making it to the output stage.

Originally the control op-amp loop was also providing gain in a non-inverting amplifier configuration so that the CMD input could be from 0-3.3V while the commanded output voltage could range from 0-4.5V.

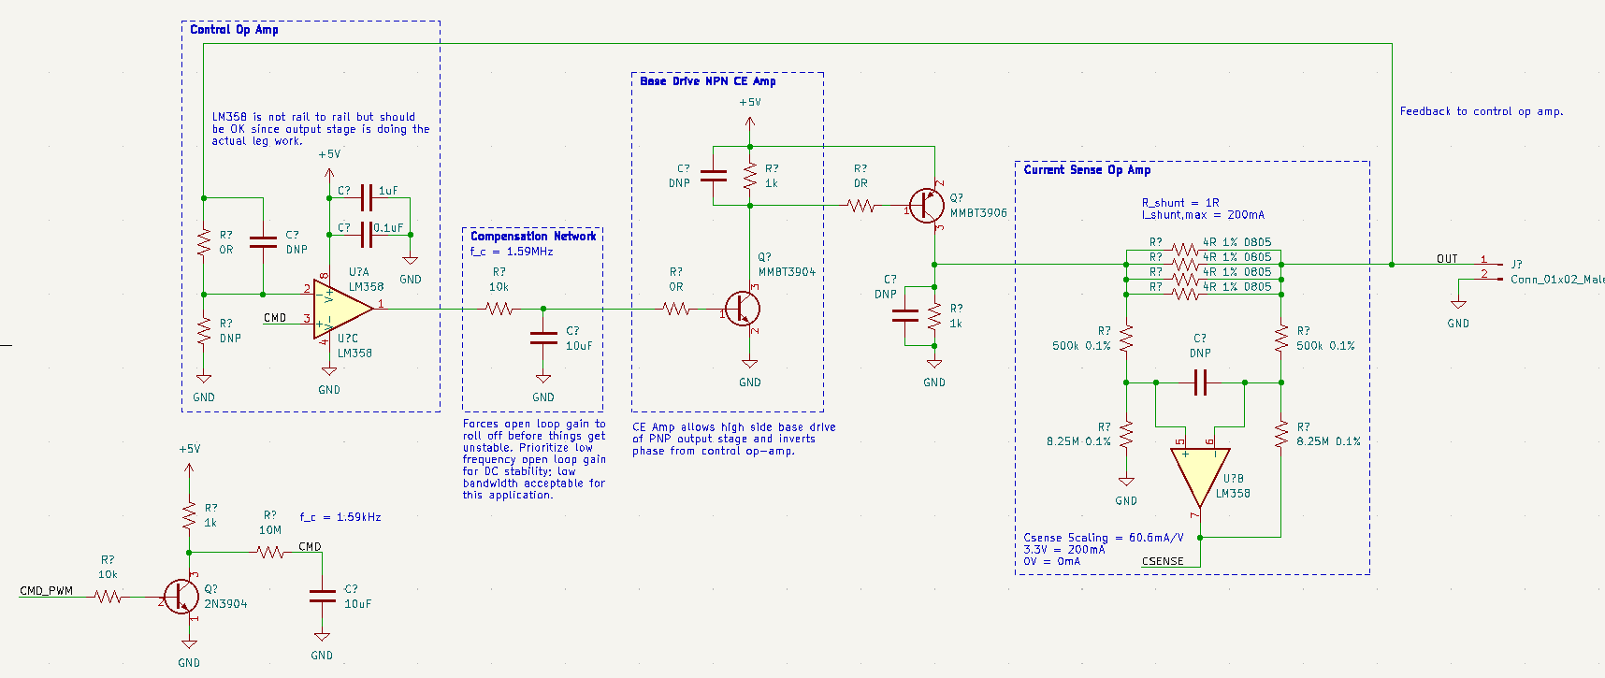
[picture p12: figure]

### AC Compensation

Oscillations are a bit of a mess (the op amp is going nuts since it’s trying to drive a BJT in voltage mode—ends up kind of like an integrator and oscillates all over the desired signal). Oscillations are either well behaved (+/- a few mV about the output waveform) or really bad (rail to rail). Rail to rail oscillations occur when the output can’t reach the target voltage due to headroom issues etc. Not desirable behavior.

An analysis of the open loop gain showed that it was more or less OK at higher frequencies. Slapping a big RC filter on the output of the op-amp tones the oscillations down a bit, but is not an elegant solution.

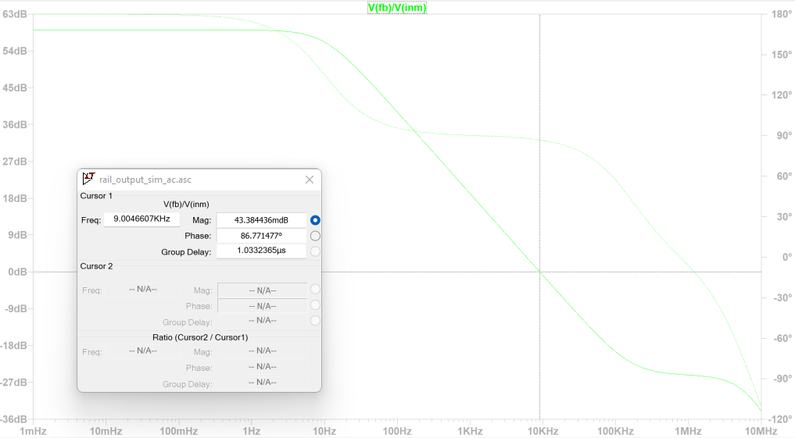
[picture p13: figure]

Left: Open loop uncompensated gain margin. Right: Open loop uncompensated phase margin.

### Breadboard Test

Test of this circuit on a breadboard worked great (used a rail to rail op amp instead of the LM358 due to the input range issues discovered in simulation), for the most part. Output was able to source 200mA into a DC load quite easily (the main issue was the power regulator on the breadboard power supply giving out). I did notice that when the breadboard regulator would shut off, the output of the simulated BMS would have a high frequency wiggle as it faded out. Although this circuit works, I don’t really like it as it’s basically PWMing the base of the BJT after the control op-amp and then using a big RC filter to try slowing the loop down enough that the output doesn’t oscillate. The result is a lot of ripple on the output (pretty low magnitude but still feels wrong on a circuit that shouldn’t really be switching constantly). Need to find a way to drive the output stage via the op-amp without the need for aggressive rail-to-rail pusles.

Demo board Rev 0.1 on breadboard. DC load + is attached on bottom right. Drove 4.5V square wave pulses into CMD input (yellow jumper, top) via a signal generator, and ran power into a DC load set to 200mA.

## Demo Board Rev 0.2 (scbs_pico REV A)

Primary motivation: remove control loop instability by reducing the gain through the control amplifier and creating a linear transfer function from error voltage to current through the base drive BJT.

The Demo Board Rev 0.1 circuit was redesigned in order to use the difference amplifier topology for its error amplification. Additional features were added to accommodate an onboard microcontroller with an isolated / level-shifted UART interface, PWM-based DAC, and SWD programming interface. A Pi Pico was chosen as the microcontroller in order to test a physical prototype, with plans to make a schematic for the STM32G4 specified in the project spec after testing.

Changing to the Pi Pico from the STM32G4 required adding a PWM filter, since it lacks the STM32’s DAC output. Tweaks were made to the error amplifier circuit such that it could be configured to add gain to the CMD channel if it was hooked to a DAC instead of PWM (gain is not necessary with PWM since it is fed into a MOSFET based level shifter and filter).

When designing the UART interface, it was decided to isolate the RX channel in order to enable it to be daisy-chained with another cell (presumably in series) with a different GND and logic HI voltage. The UART TX channel also supports daisy chaining, but assumes that the next cell in line will have an isolated RX channel, so it does not bother with isolation. UART inputs / outputs utilize 5V logic levels for improved robustness (less catastrophic if a wire gets confused with the +5V supply; this way, all input wires are +5V compatible).

No reverse polarity protection is designed for the +5V rail, but the pinout of the pin header is designed such that plugging it in backwards or offset should not cause reverse polarity on the +5V rail.

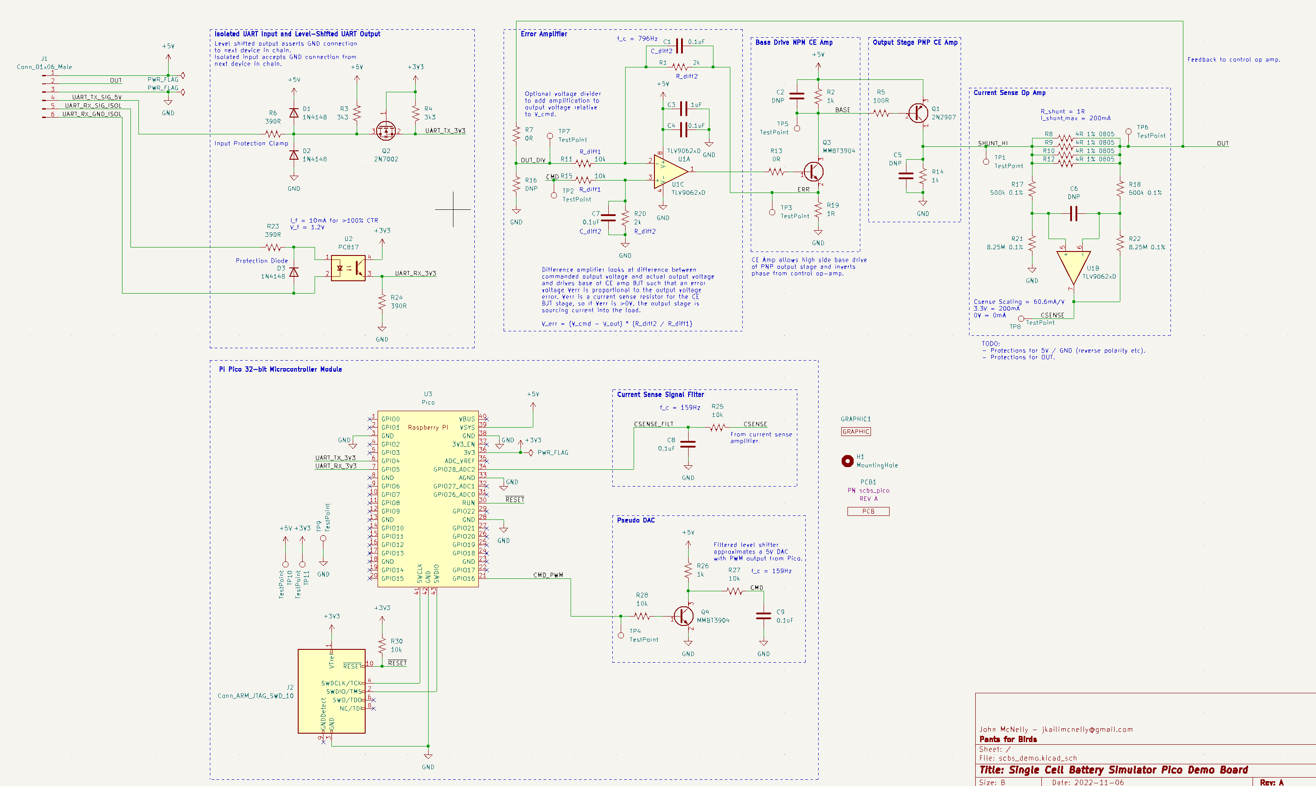
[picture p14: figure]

Error amplifier based schematic, with microcontroller added.

### Transient Simulation

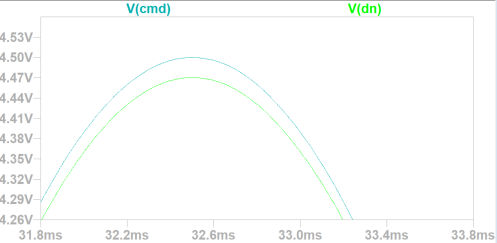
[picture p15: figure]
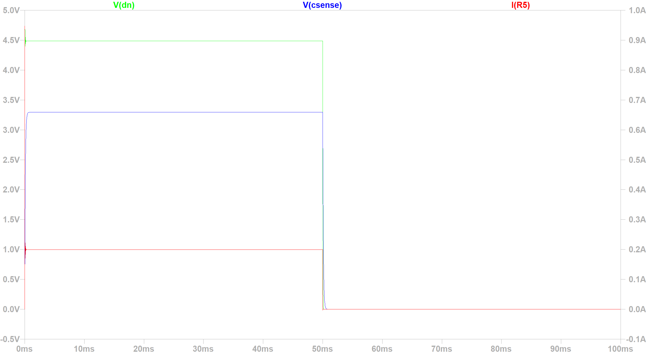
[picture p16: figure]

Left: Detailed view of undershoot when tracking a commanded sine wave, with an error amplifier voltage gain of 1/10. Larger gain results in less undershoot but less phase margin. Right: Well-behaved output in response to commanded square wave with an error amplifier voltage gain of 1/5.

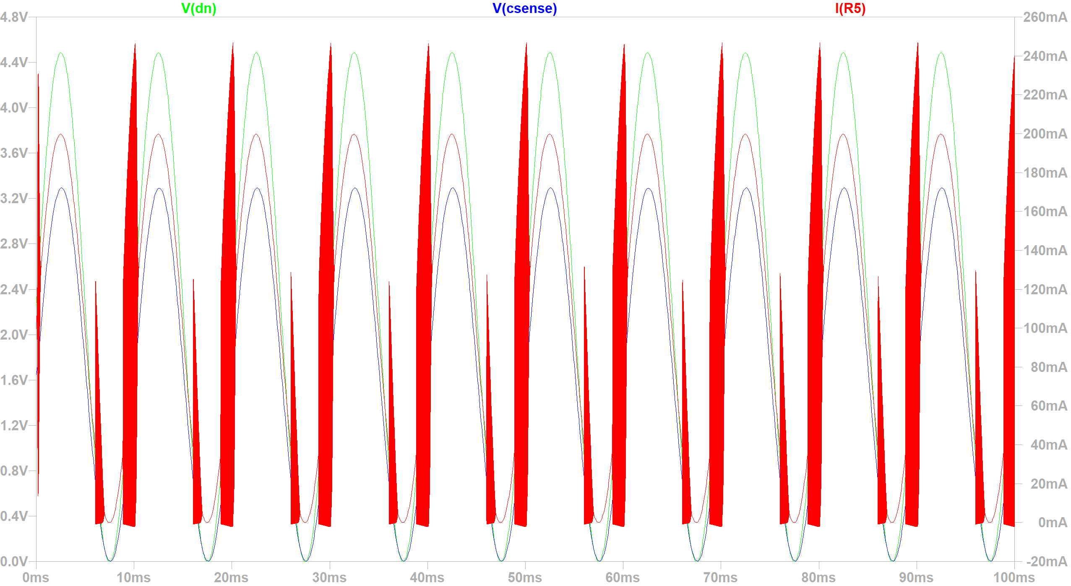
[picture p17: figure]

Left: Oscillations induced by removing bypass caps on gain setting resistors in the error amplifier circuit. Right: Oscillations induced by setting error amplifier voltage gain to 1.

### AC Simulation

Using a low error amplifier gain is important for creating enough phase margin to avoid oscillations on the output stage. Increasing from a gain of 1/5 to a gain of 1 creates instability in AC and transient analysis. Adding bypassing to the error amplifier circuit is also important for avoiding oscillations. A corner frequency slightly above 1.5kHz was chosen for convenience and seems to work pretty well.

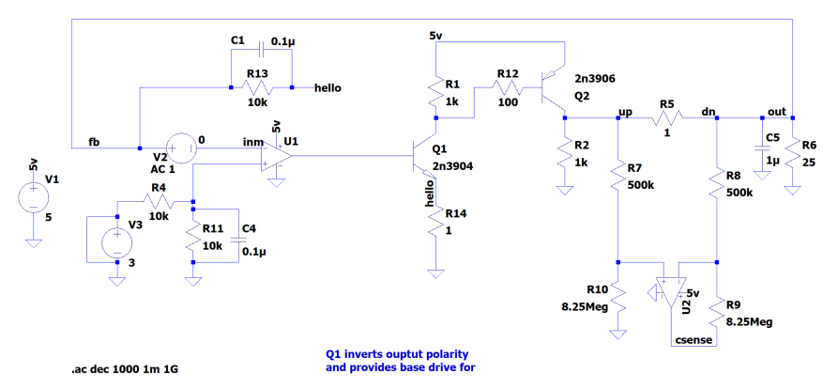
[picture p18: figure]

LTSpice schematic used for AC analysis.

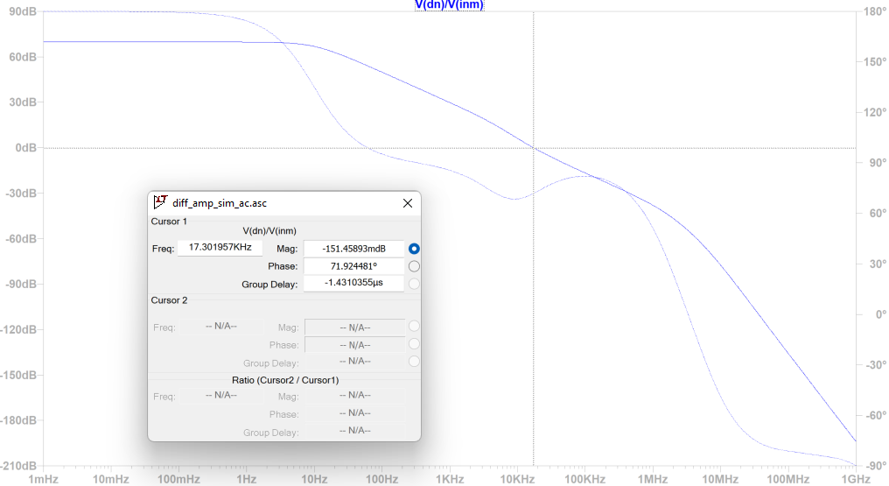
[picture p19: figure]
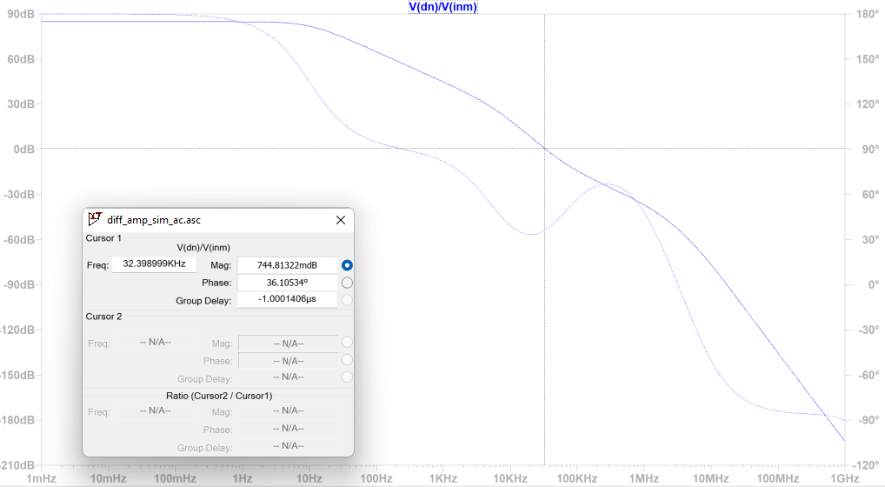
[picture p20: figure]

Left: Phase margin with error amp gain of 1/5. Right: Phase margin with error amp gain of 1.

### Homebrew PCB Prototype

2x pico_scbs boards were etched using a toner transfer process. Additional toner was applied to the top layer as legend. Boards are single sided. Note that Pi Pico needs to be populated for testing since it is used for sharing ground connections due to routing constraints.

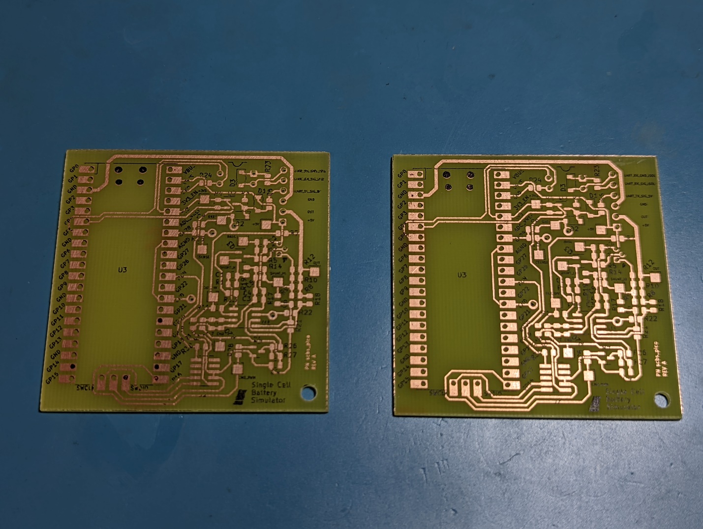
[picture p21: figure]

Notable changes when populating the board:

- Didn’t have 4 Ohm resistors for the shunt resistor, approximated with 3x 3.9 Ohm resistors in parallel with 1x 4.3 Ohm resistor.
- Didn’t have 500 kOhm resistors, swapped with 510 kOhm resistors.

Notable changes during bringup:

- Chasing my tail while the output stage PNP was backwards…
  - Changed R5 to 0 Ohms to try increasing base current to output stage PNP transistor. Later changed back to 100 Ohms.
  - TLV9062 has minimum open loop gain of around 100dB (10k), whereas the op-amp used in sim had an open-loop gain of 10M. There might be an issue with not enough gain for properly closing the loop.
  - As load increases, output voltage decreases until it suddenly drops off a cliff. Turns out my generic Amazon 2N2907 PNP BJT on the output was completely flipped! The generic device I had is EBC not CBE like the legit manufacturer device (pins in ascending order). Transistor tester saved the day.
- Testpoint ERR is mistakenly labeled SHUNT_HI on legend.

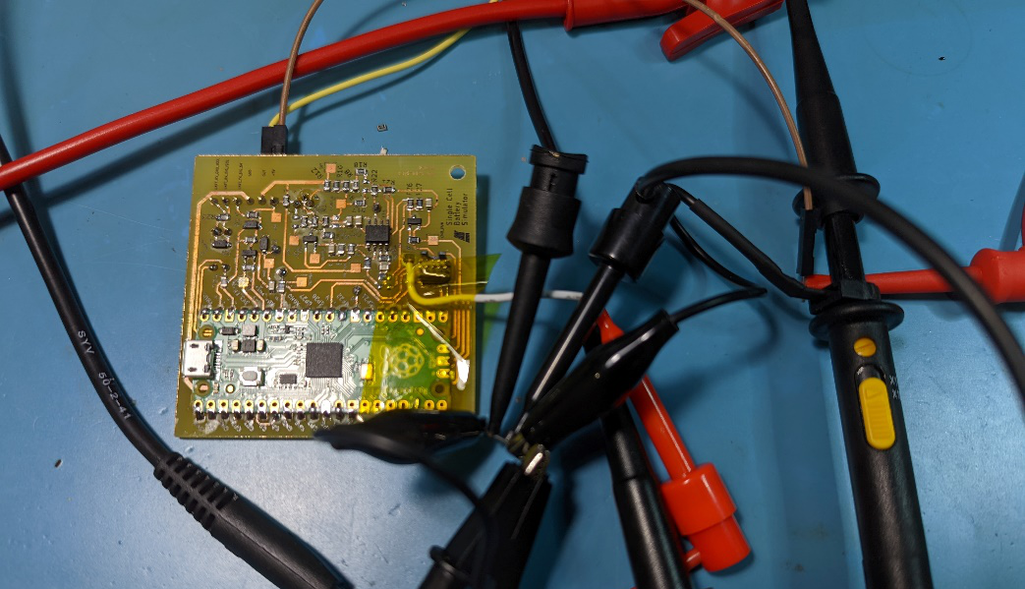
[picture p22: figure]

Homebrew PCB was tested with 5VDC power supply, DC load, signal generator, and 2x oscilloscope channels. Analog portion of the board was brought up first with commanded output voltage signal injection via the white wire hooked to the CMD net.

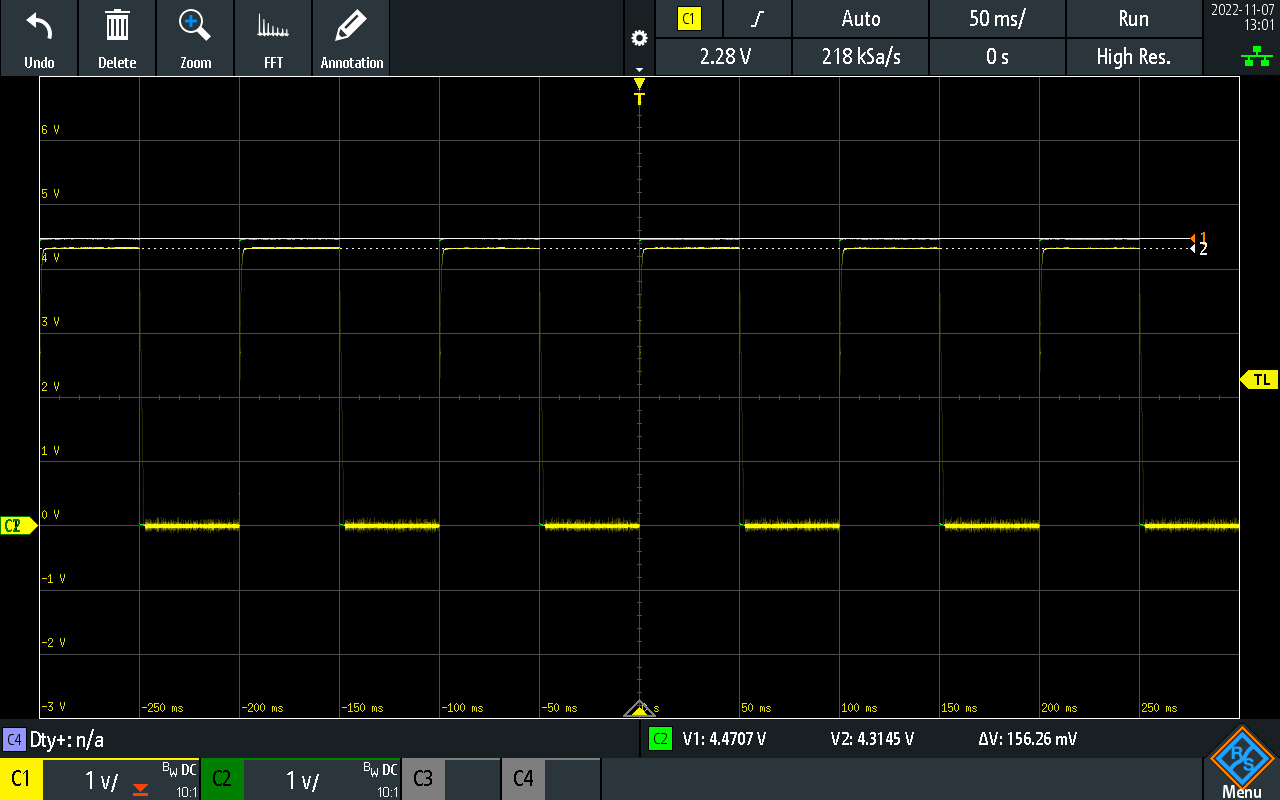
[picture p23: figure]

CMD Input (CH2, green) and OUT output (CH1, yellow) waveforms showing tracking for a 10Hz 0-4.5V square wave. Output is 3.3% below commanded voltage (within spec).

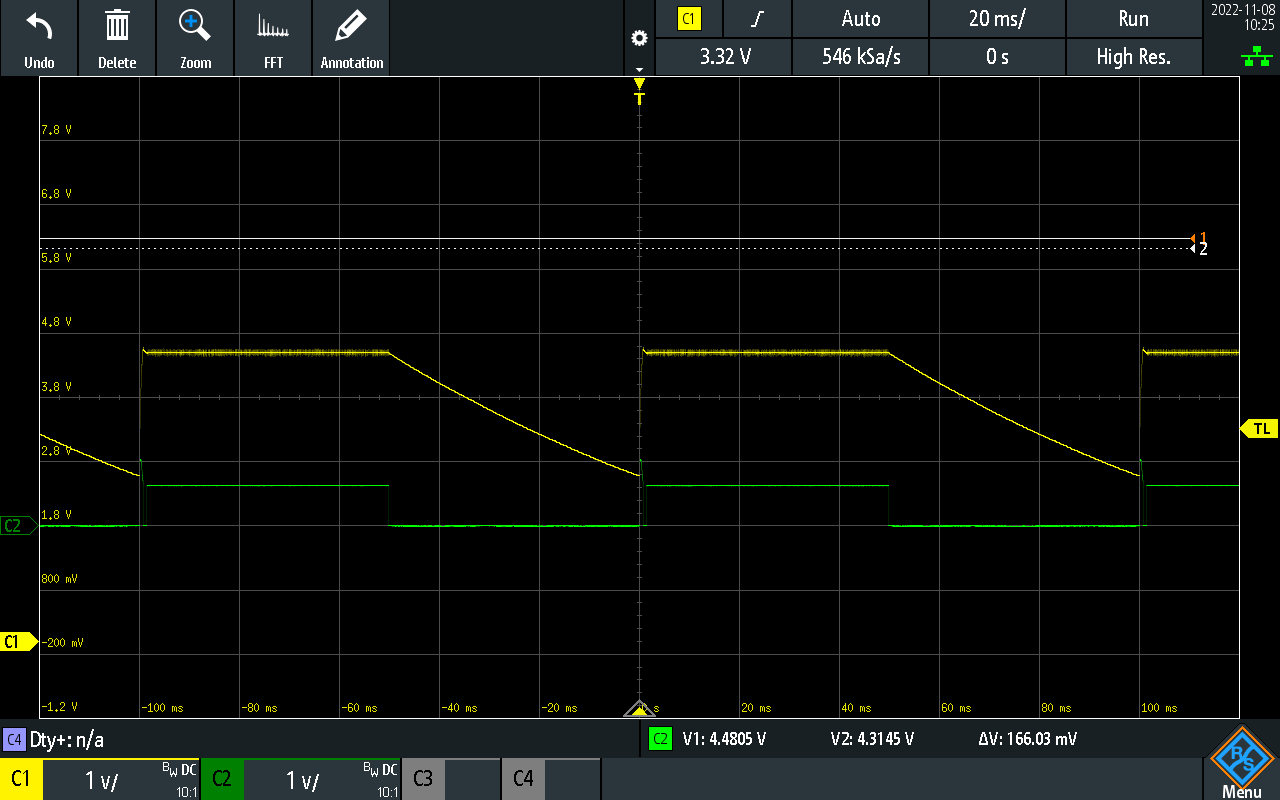
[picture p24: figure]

Output not responding to 1Hz square wave (slew rate super low), I think Q3 might be fried? CH1 (Yellow) is OUT. Ch2 (Green) is base of Q3. Haha I’m dumb, DC load wasn’t on.

- Output current sense is giving around half of the expected voltage.
  - LTSPice simulation with worse case offset voltage on current sense amp doesn’t show anything weird.
  - Best guess is that 8.25M is too big a value for the feedback resistors on the current sense op-amp, maybe they’re getting loaded by other parts of the circuit? Seems wrong though. Doesn’t seem likely. Conductive flux in parallel with the large resistors is a possibility, cleaned the board to see if that would make a difference.
  - Found the issue (probably)! Output current sense resistor is around 0.7Ohms instead of 1Ohm. Need to get better resistors, add a trim pot, or correct in software.

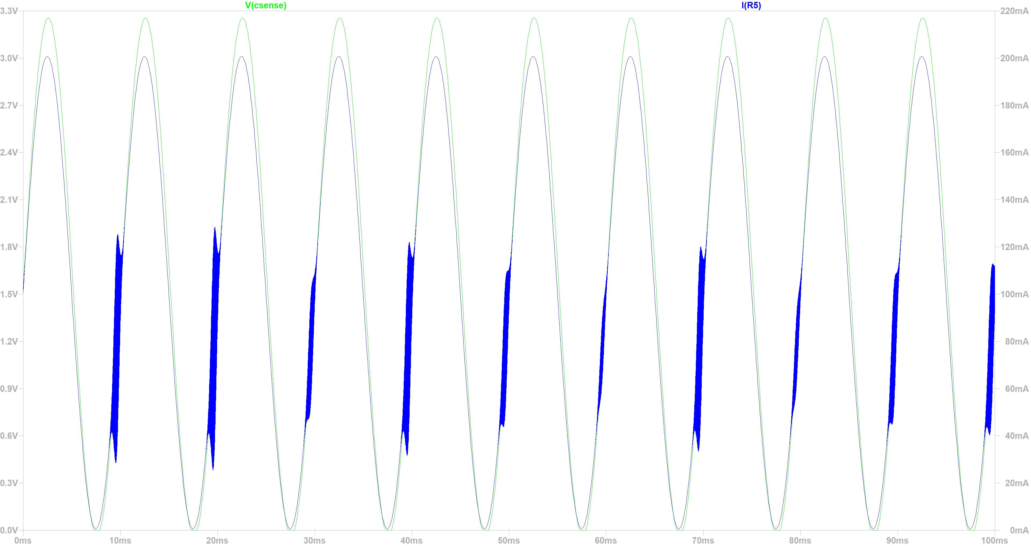
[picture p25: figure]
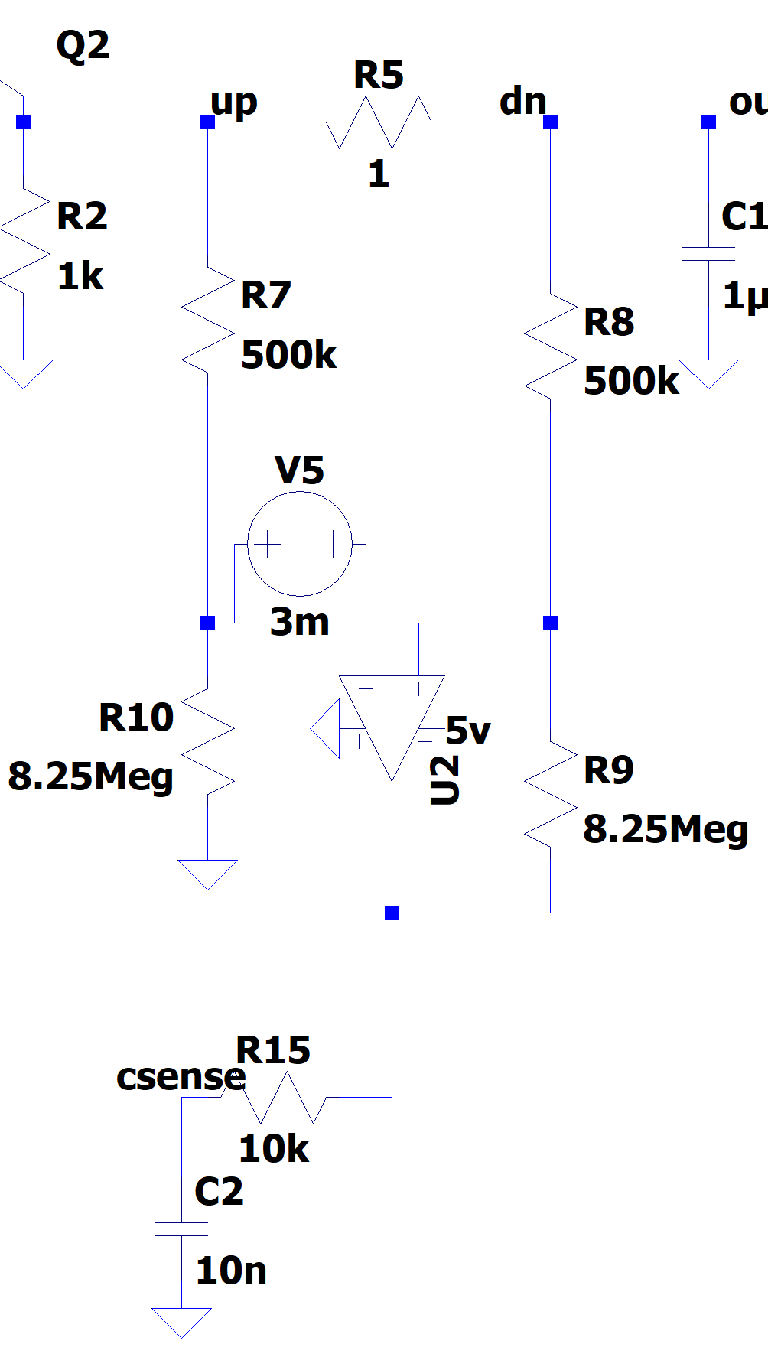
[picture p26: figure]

Doesn’t seem to be caused by offset voltage on current sense amp.

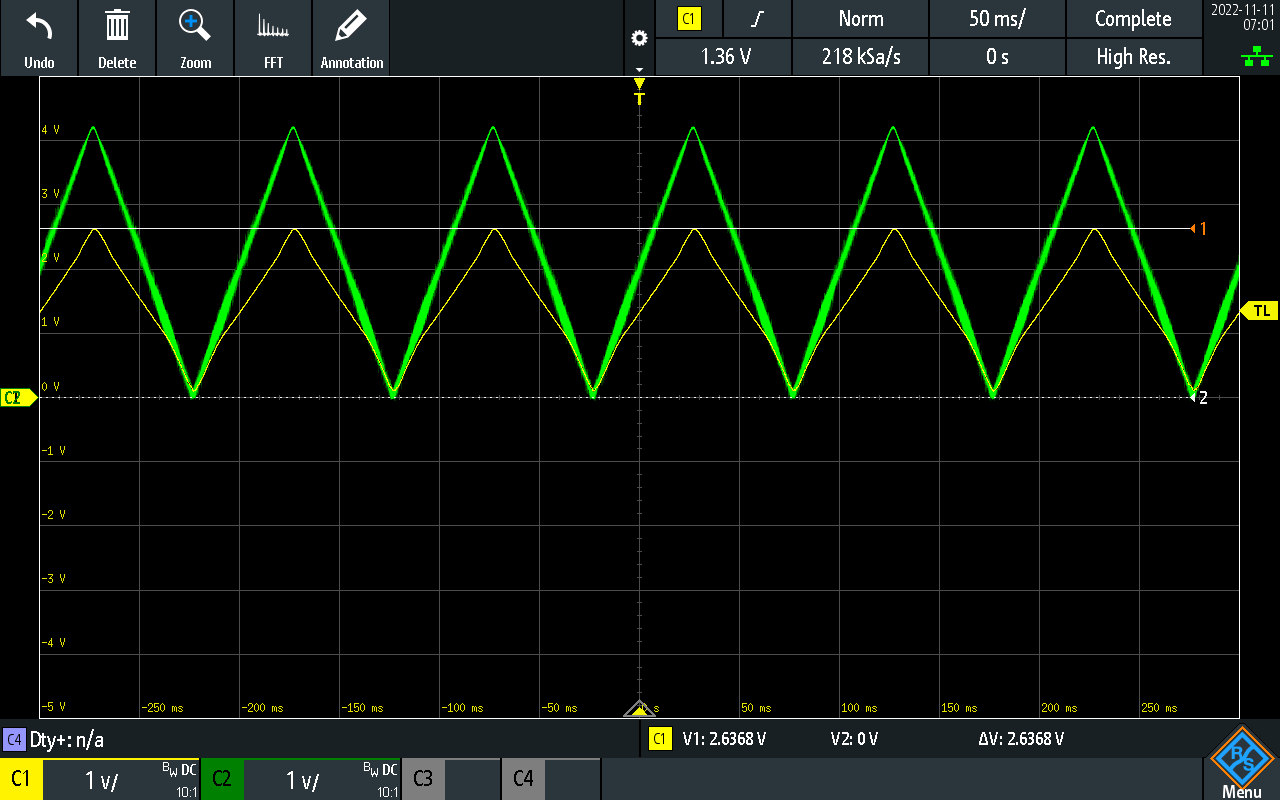
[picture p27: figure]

20Ohm load (250mA) with 4.5V input waveform. CH1 is current sense, CH2 is output voltage.

- PWM Output voltage issues: with 50% duty cycle, seeing 1.65V out average at the GPIO pin, but only around 1.2V at the CMD testpoint.
  - Input voltage divider on difference amplifier V+ pin is loading down the PWM circuit too much.

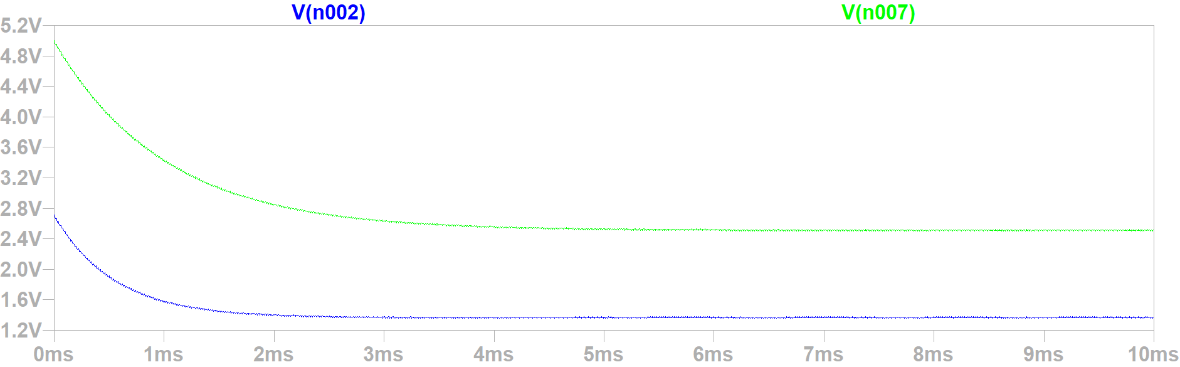
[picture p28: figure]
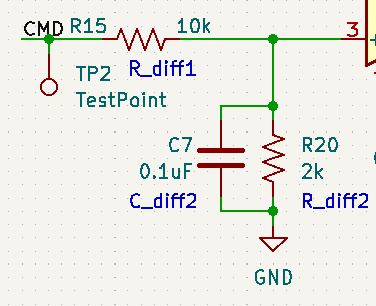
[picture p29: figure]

Left: PWM output voltage at 50% duty cycle without diff amp input (green), and with diff amp input (blue). Right: diff amp input. Need to up these impedances a bit.

Changing diff amp input resistors to 10M and 2M fixes the issue.

- Changed R11, R15 to 10MOhms and R1, R20 to 2Mohms, changed C1, C7 to 100pF to match bandwidth, but it created a noise issue.
  - Tried cutting error amplifier bandwidth by increasing C1, C7 to 1nF and then back to 100nF, but output noise issue still remained.
  - Maybe some kind of noise issue with higher crosstalk with the larger resistor values on the error amplifier circuit?

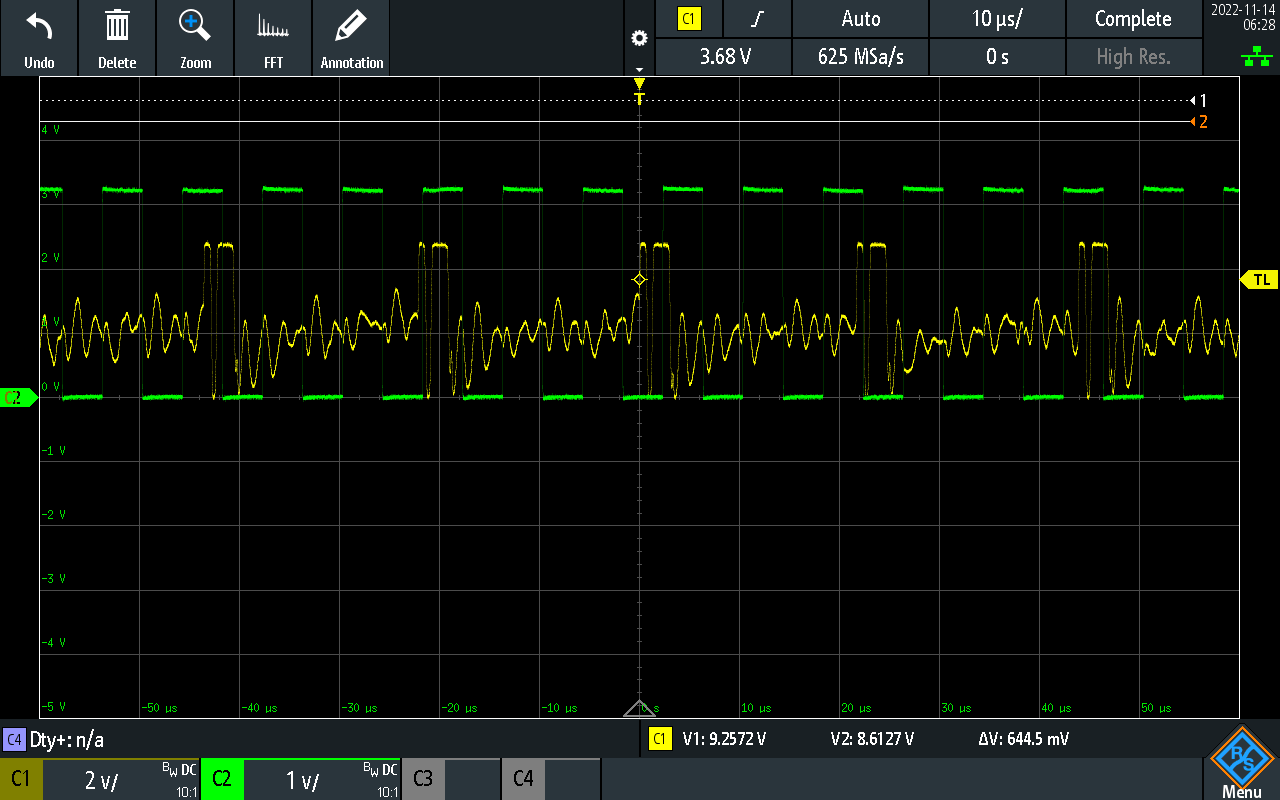
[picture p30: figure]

Green shows CMD_PWM, yellow shows OUT. Output oscillates aggressively.

- We only really need the high impedance on R15 and R20, and R11 / R1 are in a really long feedback loop (maybe more noise). Try changing R1 and R11 back to previous value of 10k / 2k.
- Additional Modifications
  - Removed the cap on the output BJT base, oscillations were really caused by insufficient base resistor on output BJT. Upgraded base resistor to 10k and that stopped the oscillations, but caused voltage sag when supplying max output current (200+mA) due to insufficient base current before the base drive voltage dropped to 0V. Experimented with some values and 750R was good enough for the base resistor to have no oscillations with an unloaded output, and was able to supply up to 200mA on the output without much difficulty. Could probably go even lower if required.
  - Added 10uF capacitor to the output to smooth out any wiggles (high freq noise, not really the issue from before with the output BJT oscillating of its own volition) and provide more instantaneous current capacity (like a battery cell). Electrolytic output cap with some moderate ESR was nice for avoiding the wiggles (ceramic cap not as good).

# SCBS Array

## UART Daisy Chaining Issue

Noticed that when chaining UARTs together, the UART output was able to drive the USB to UART converter’s input just fine, but failed to drive the opto-isolator LED of the next cell in line. Realized that output was driving with high impedance.

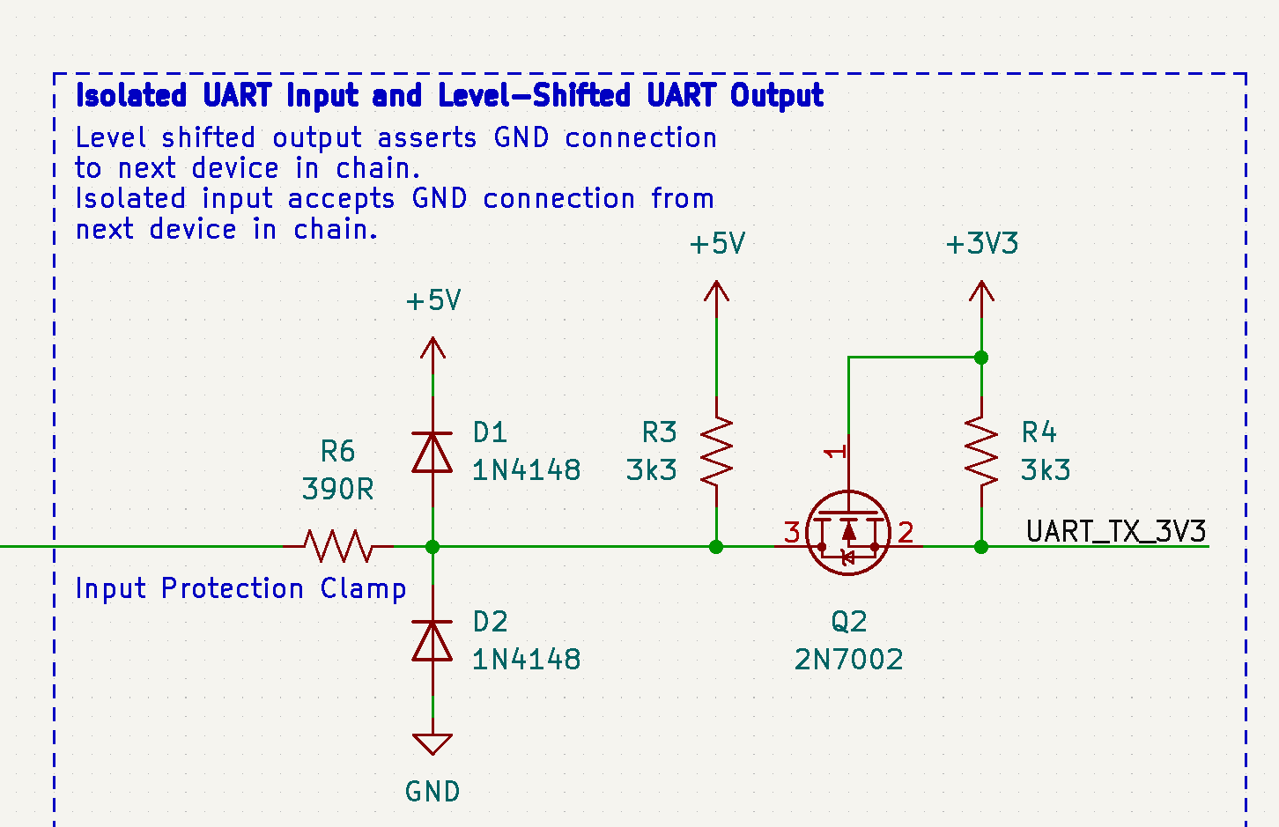
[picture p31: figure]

Replaced D1/D2/R6 protection circuit with an emitter follower stage using a MMBT3904 and a 3k3 pulldown resistor. Managed to bodge it in onto the footprint where D1 previously resided, plus a GND trace adjacent to the output pin.

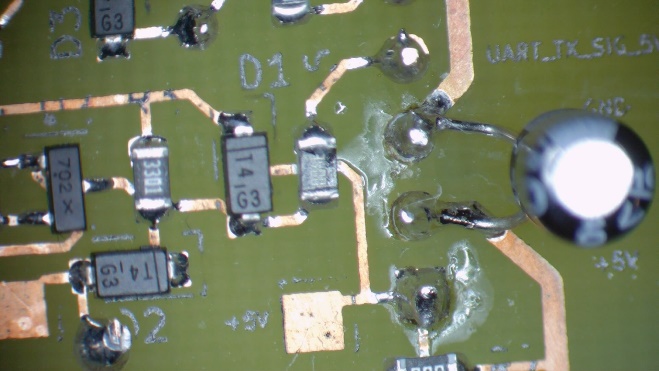
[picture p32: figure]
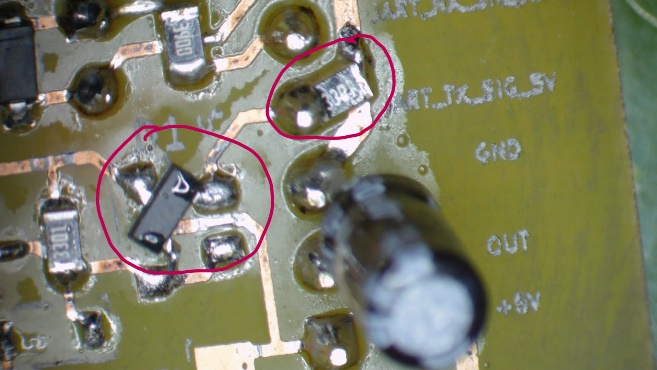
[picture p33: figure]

Left: Unmodified high impedance output. Right: Output stage modified with emitter follower in place of transient protection circuit.

## Cells in Series Daisy Chaining Issue

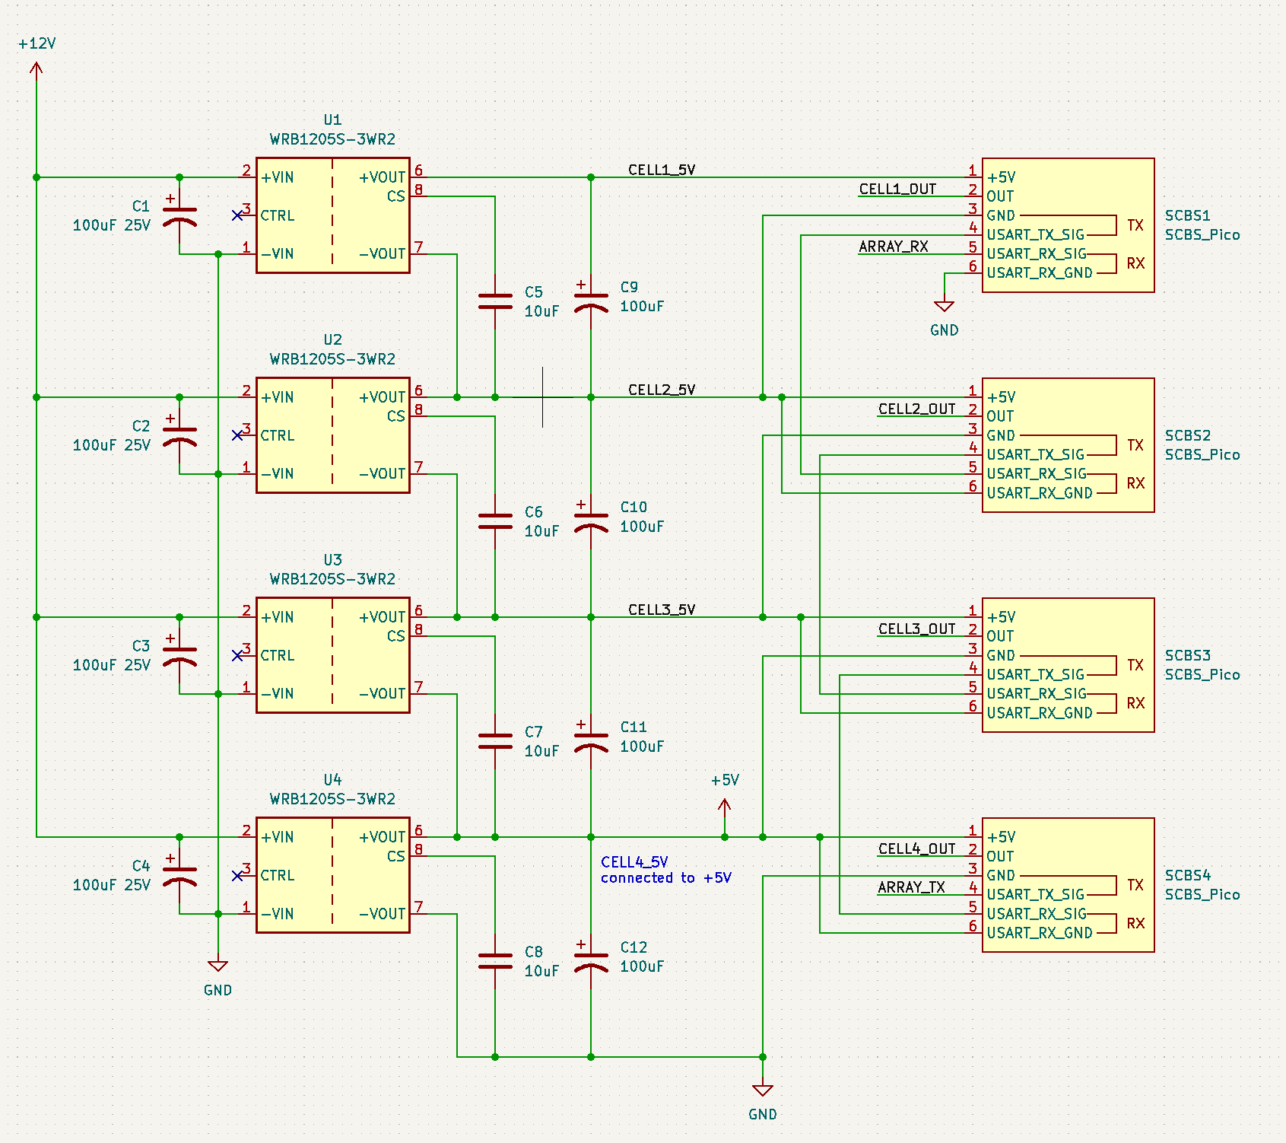
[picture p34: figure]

This is incorrect! Chaining +5V from one cell to the GND of the next. Need to chain CELL(N)_OUT to CELL(N+1)_OUT.

## Mismatched Output Voltages

Some cells were outputting 2.55V while others were outputting around 2.22V with the same output voltage setting. It was determined that the PWM transistor had an effect on the commanded output voltage on the CMD net. The 2.55V cell was using a MMBT3904L1TG NPN BJT, while the 2.22V cell was using an MMBT3904-7-F. All CMD PWM BJT’s were changed to MMBT3904L1TG to make calibration work easily.

## Output of Cell 4 Shorted

Cell 4 was getting really hot (SCBS4 position, cell serial number 1). Issue was traced to a short on the motherboard under a jumper resistor. Short was cleared and board resumed functioning normally.

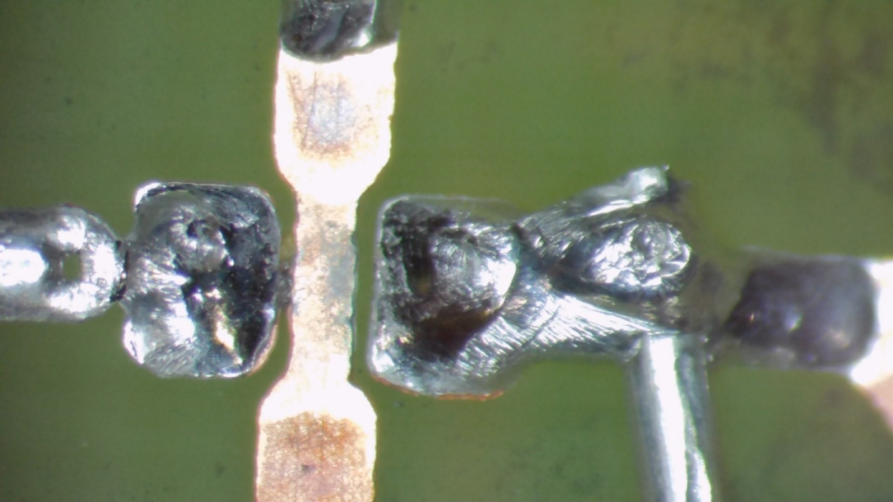
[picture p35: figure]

## Cell Serial Number 1 Being Weird

Around 24hrs into a burn-in test (2.5V output voltage with 200mA load in enclosure), Cell serial number 1 failed (output voltage sagging from 4.5V to 3.4V under a 200mA load). Attributed failure to driving a short for a while before the 24 hour burn-in.

Replaced output 2N2907 and output improved somewhat (sagging from 4.5V to 4.3V under a 200mA load). After output transistor replacement, cell serial 1 still lagging behind other cells (sag from 4.5V to 4.4V is nominal).

Noticed that base drive voltage of output 2N2907 was significantly below other cells (base drive was around 0.4V when driving 200mA@2.5V, instead of 1.1V for other cells). Replaced base drive transistor (was the non-L1TG version of MMBT3904, thought it might make a difference). No change.

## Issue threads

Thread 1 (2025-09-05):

Does this battery emulator also sink current?

redfast00, 2025-09-05:

CoolNamesAllTaken, 2025-09-05:
This generally only sources current since passive balancers just sink current.

redfast00, 2025-09-05:
Right, good to know :) Guess I'll use another project then, I want to simulate an entire battery, both sinking and sourcing current to check if the protections/charging profiles work

CoolNamesAllTaken, 2025-09-05:
No worries, best of luck!

Closed 2025-09-05.

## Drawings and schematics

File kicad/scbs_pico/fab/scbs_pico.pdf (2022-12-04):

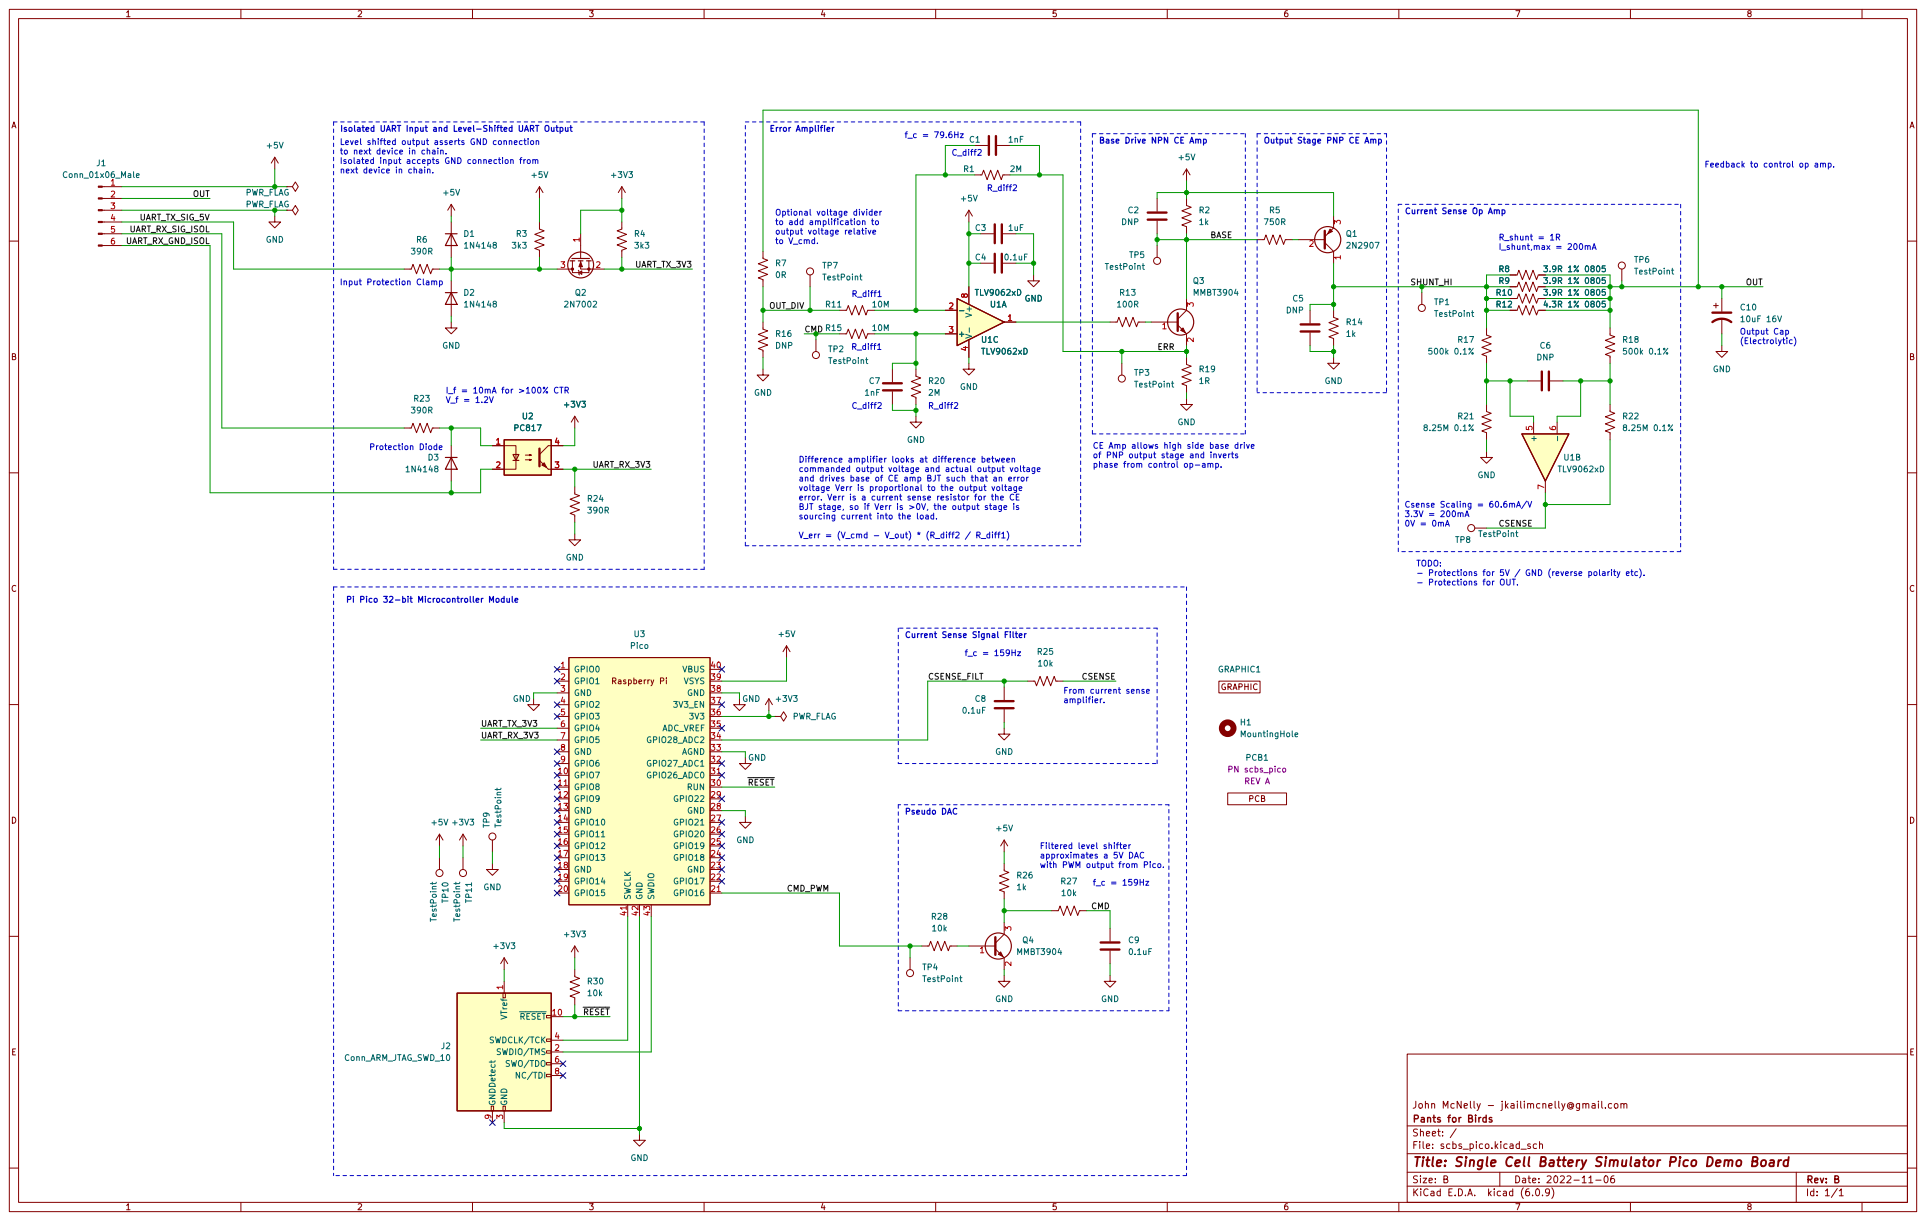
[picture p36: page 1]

Isolated UART Input and Level-Shifted UART Output
Level shifted output asserts GND connection
to next device in chain.
Isolated input accepts GND connection from

Base Drive NPN CE Amp

Feedback to control op amp.

Optional voltage divider
to add amplification to
output voltage relative
to V_cmd.

CE Amp allows high side base drive
of PNP output stage and inverts
phase from control op-amp.

commanded output voltage and actual output voltage
and drives base of CE amp BJT such that an error
voltage Verr is proportional to the output voltage
error. Verr is a current sense resistor for the CE
BJT stage, so if Verr is >0V, the output stage is
sourcing current into the load.

Filtered level shifter approximates a 5V DAC

3 SWDCLK/TCK 4 SWO/TDO 6 NC/TDI 8 GNDDetect 9

John McNelly - jkailimcnelly@gmail.com
File: scbs_pico.kicad_sch Sheet: / Pants for Birds

Id: 1/1 Title: Single Cell Battery Simulator Pico Demo Board

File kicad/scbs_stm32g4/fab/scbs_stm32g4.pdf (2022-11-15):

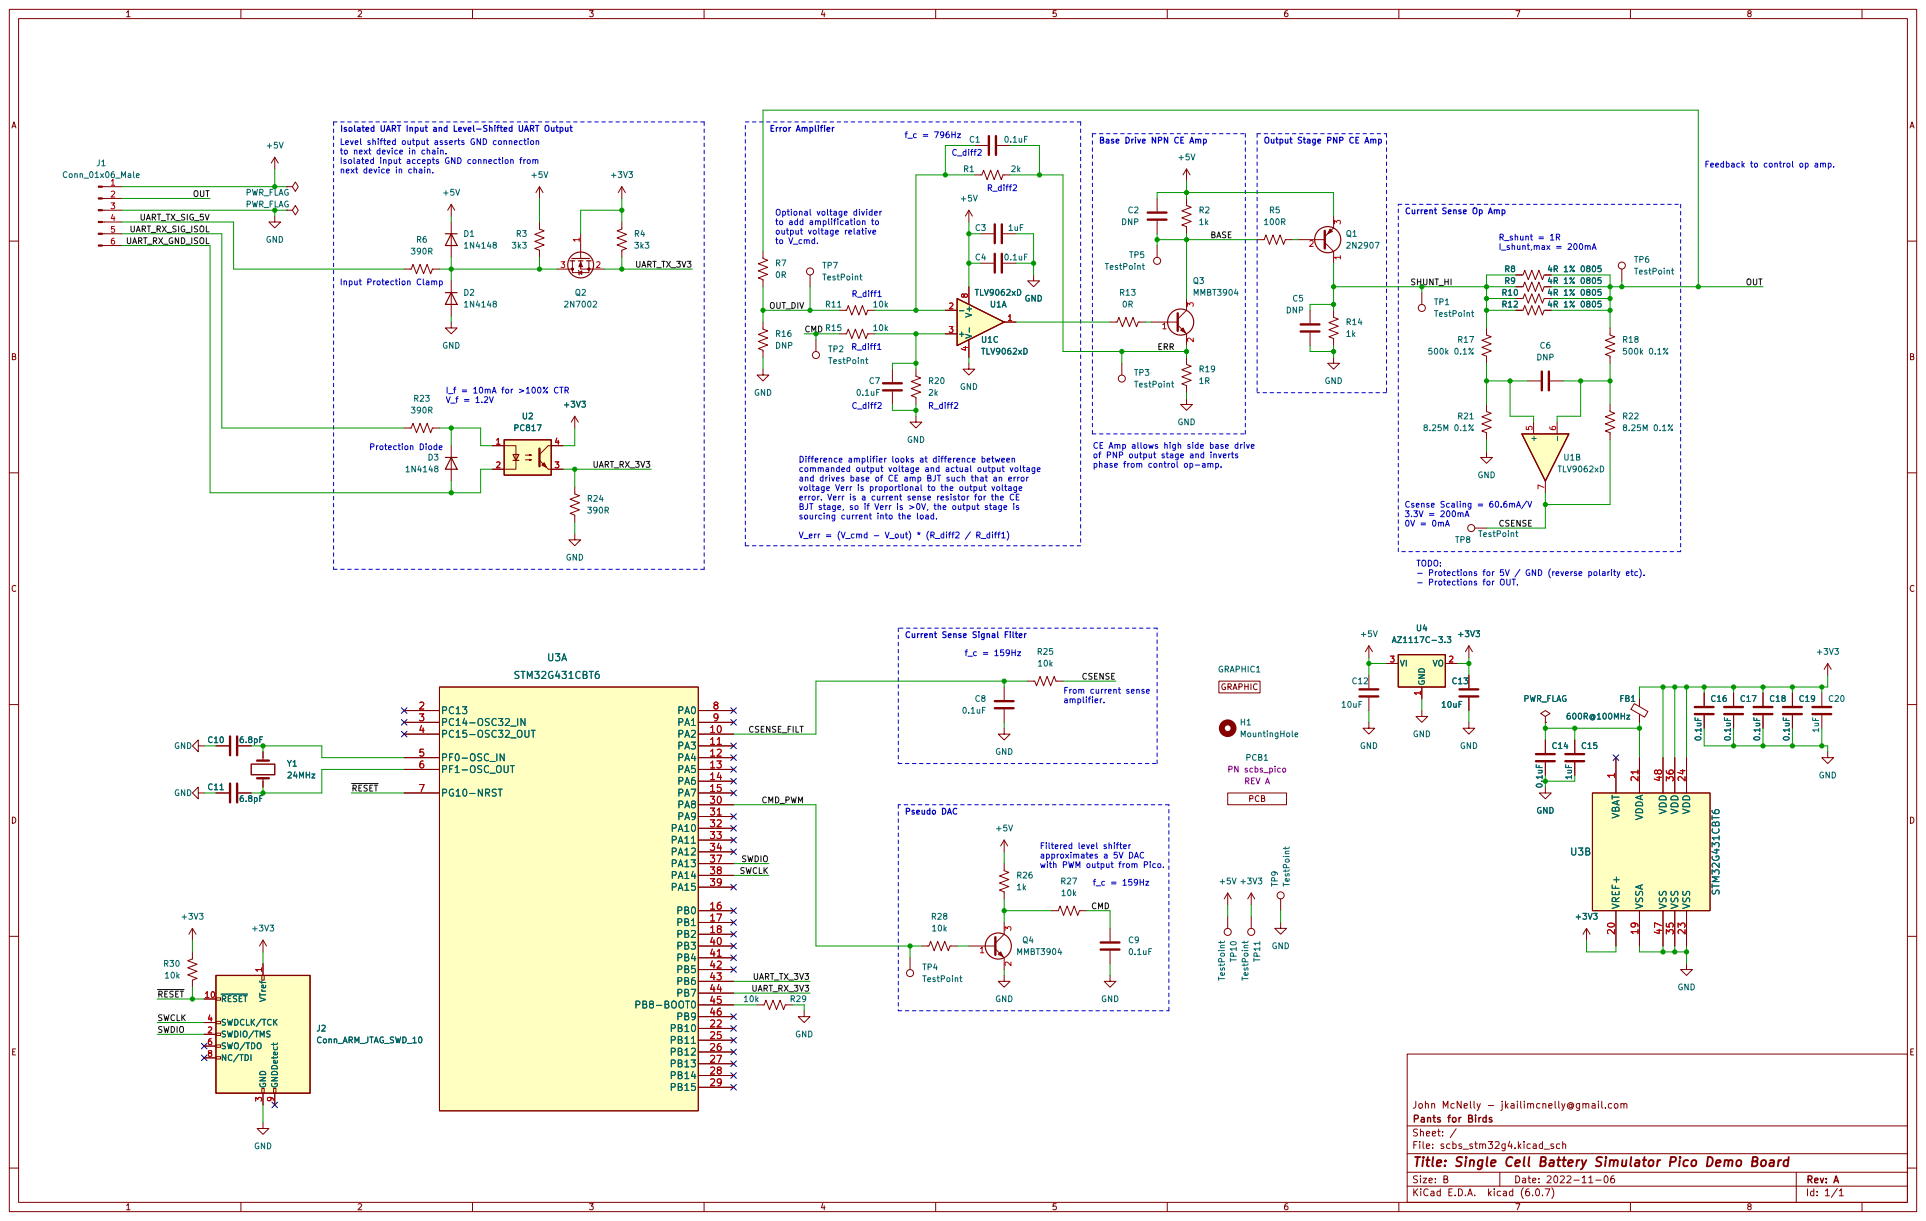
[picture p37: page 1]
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

to add amplification to
output voltage relative

R_diff1 Difference amplifier looks at difference between

3 SWDCLK/TCK 4 SWO/TDO 6 NC/TDI 8 GNDDetect 9 U2 PC817

CE Amp allows high side base drive
of PNP output stage and inverts

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

1 VSSA 19 VREF+ 20 VDDA 21 VSS 23 VDD 24 VSS 35 VDD 36 VSS 47 VDD 48 U3B STM32G431CBT6

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

with PWM output from Pico.

3 SWDCLK/TCK 4 SWO/TDO 6 NC/TDI 8 GNDDetect 9

John McNelly - jkailimcnelly@gmail.com
File: scbs_stm32g4.kicad_sch Sheet: / Pants for Birds

Id: 1/1 Title: Single Cell Battery Simulator Pico Demo Board

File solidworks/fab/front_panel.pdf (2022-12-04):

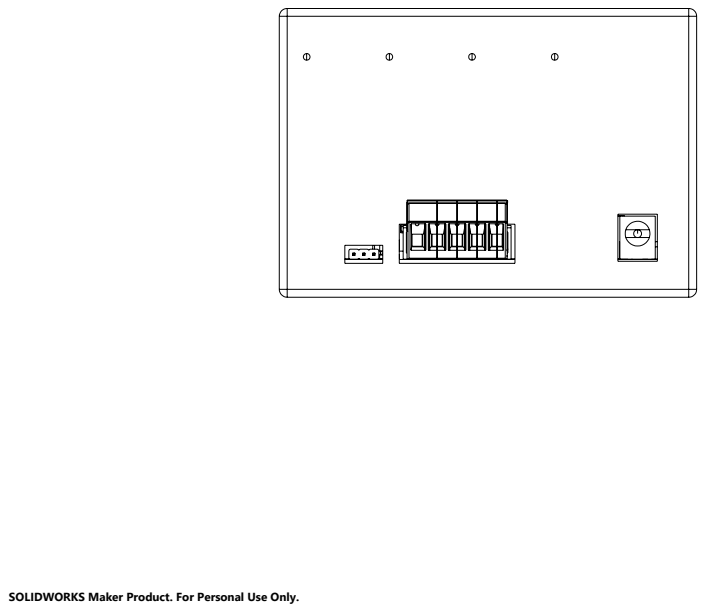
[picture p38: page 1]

SOLIDWORKS Maker Product. For Personal Use Only.

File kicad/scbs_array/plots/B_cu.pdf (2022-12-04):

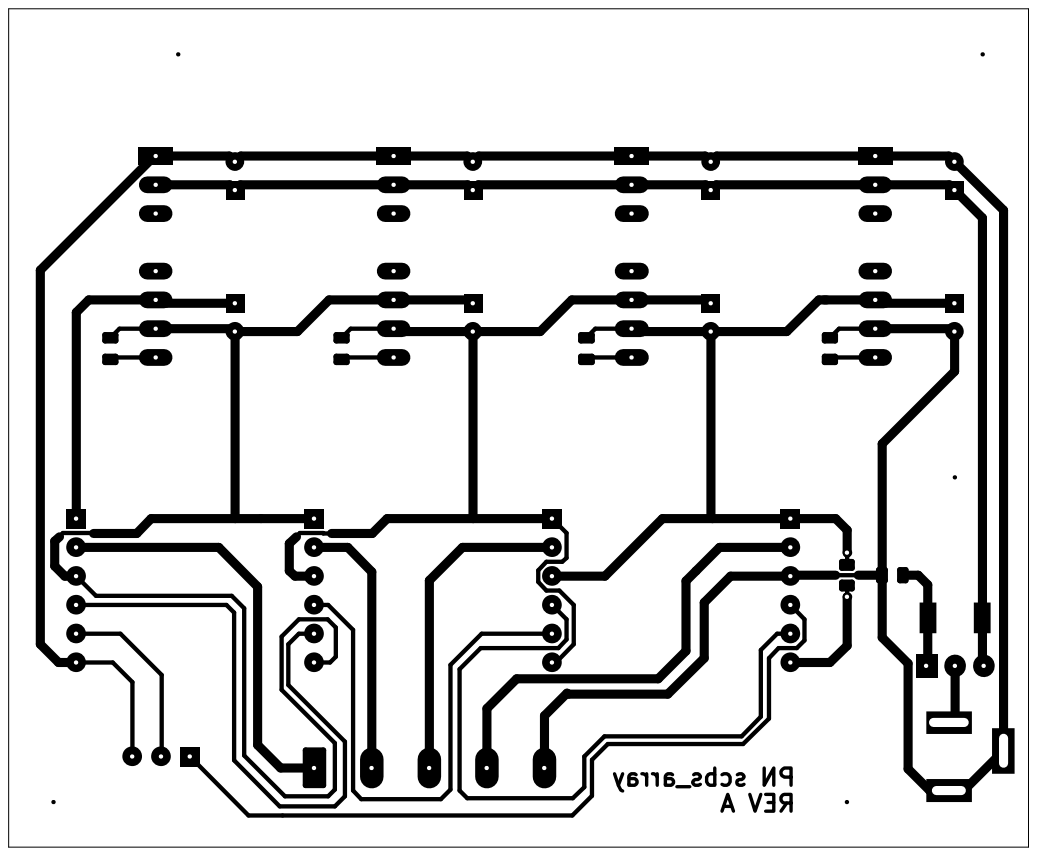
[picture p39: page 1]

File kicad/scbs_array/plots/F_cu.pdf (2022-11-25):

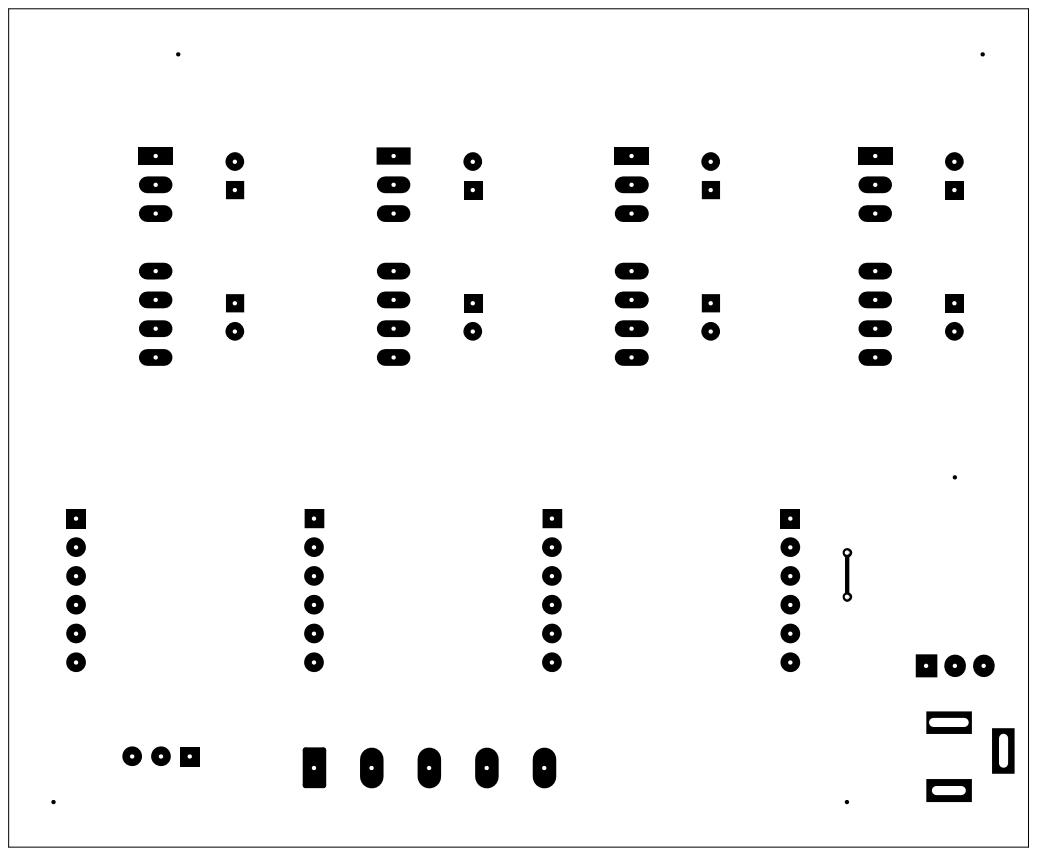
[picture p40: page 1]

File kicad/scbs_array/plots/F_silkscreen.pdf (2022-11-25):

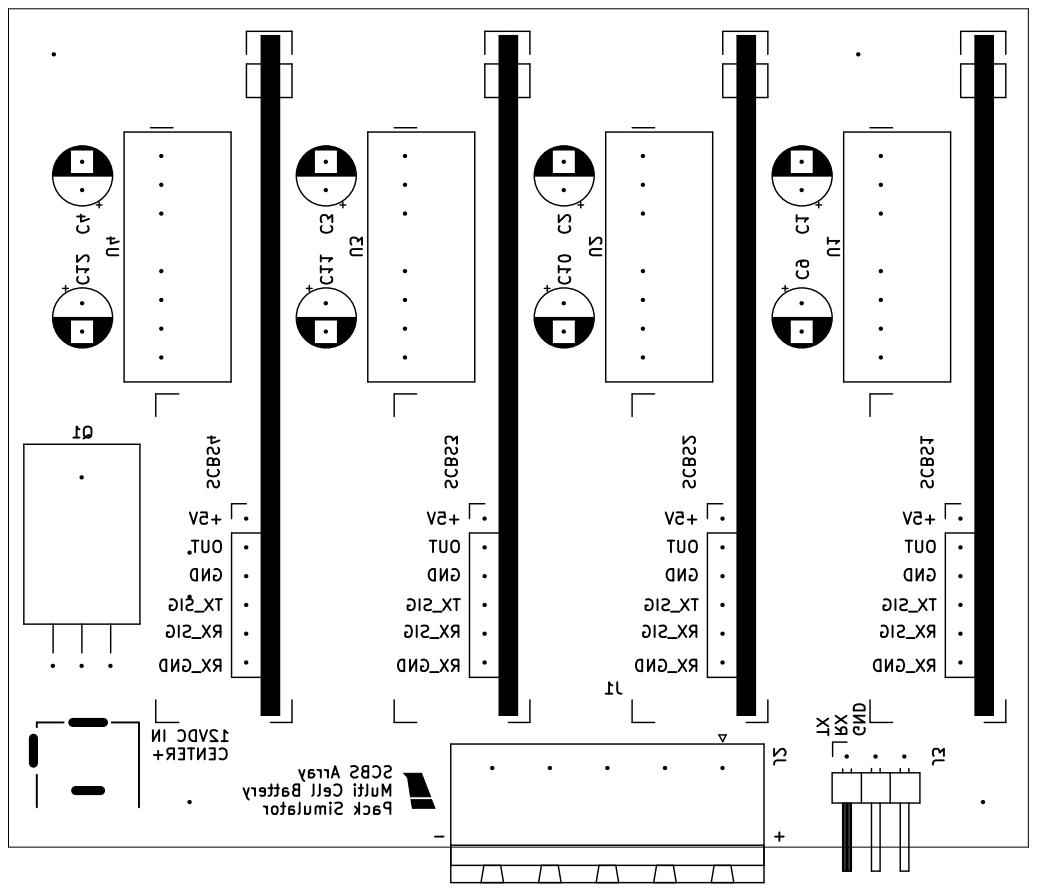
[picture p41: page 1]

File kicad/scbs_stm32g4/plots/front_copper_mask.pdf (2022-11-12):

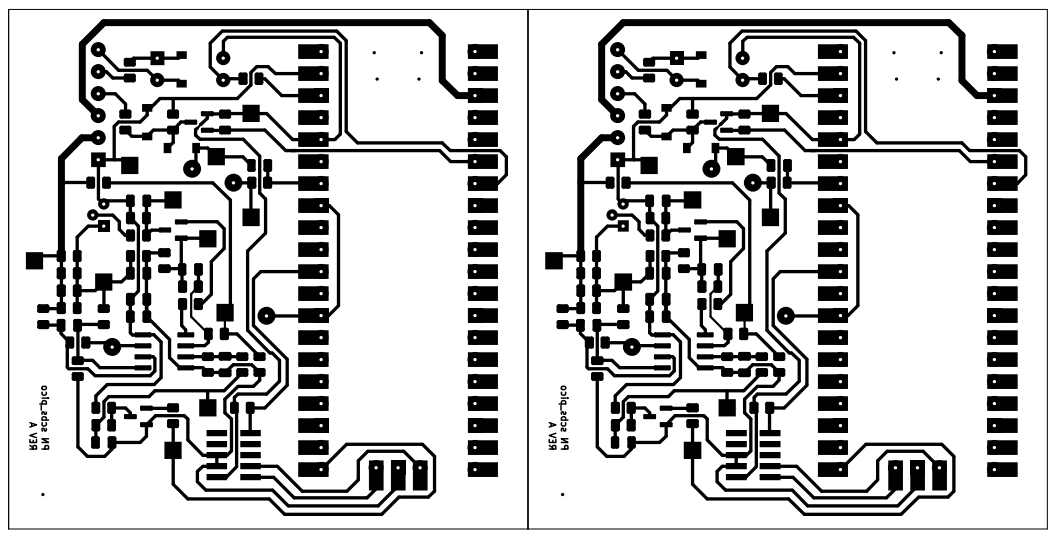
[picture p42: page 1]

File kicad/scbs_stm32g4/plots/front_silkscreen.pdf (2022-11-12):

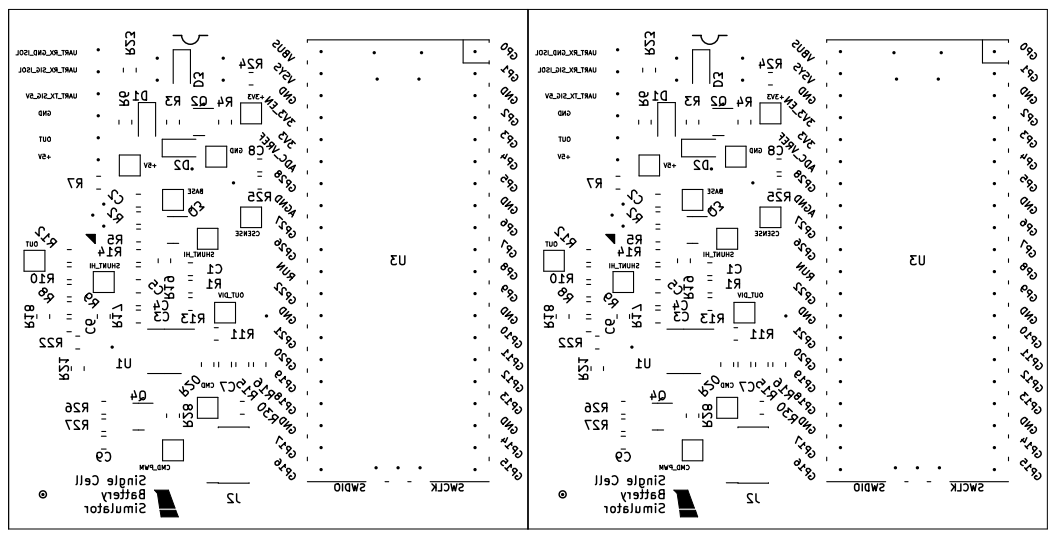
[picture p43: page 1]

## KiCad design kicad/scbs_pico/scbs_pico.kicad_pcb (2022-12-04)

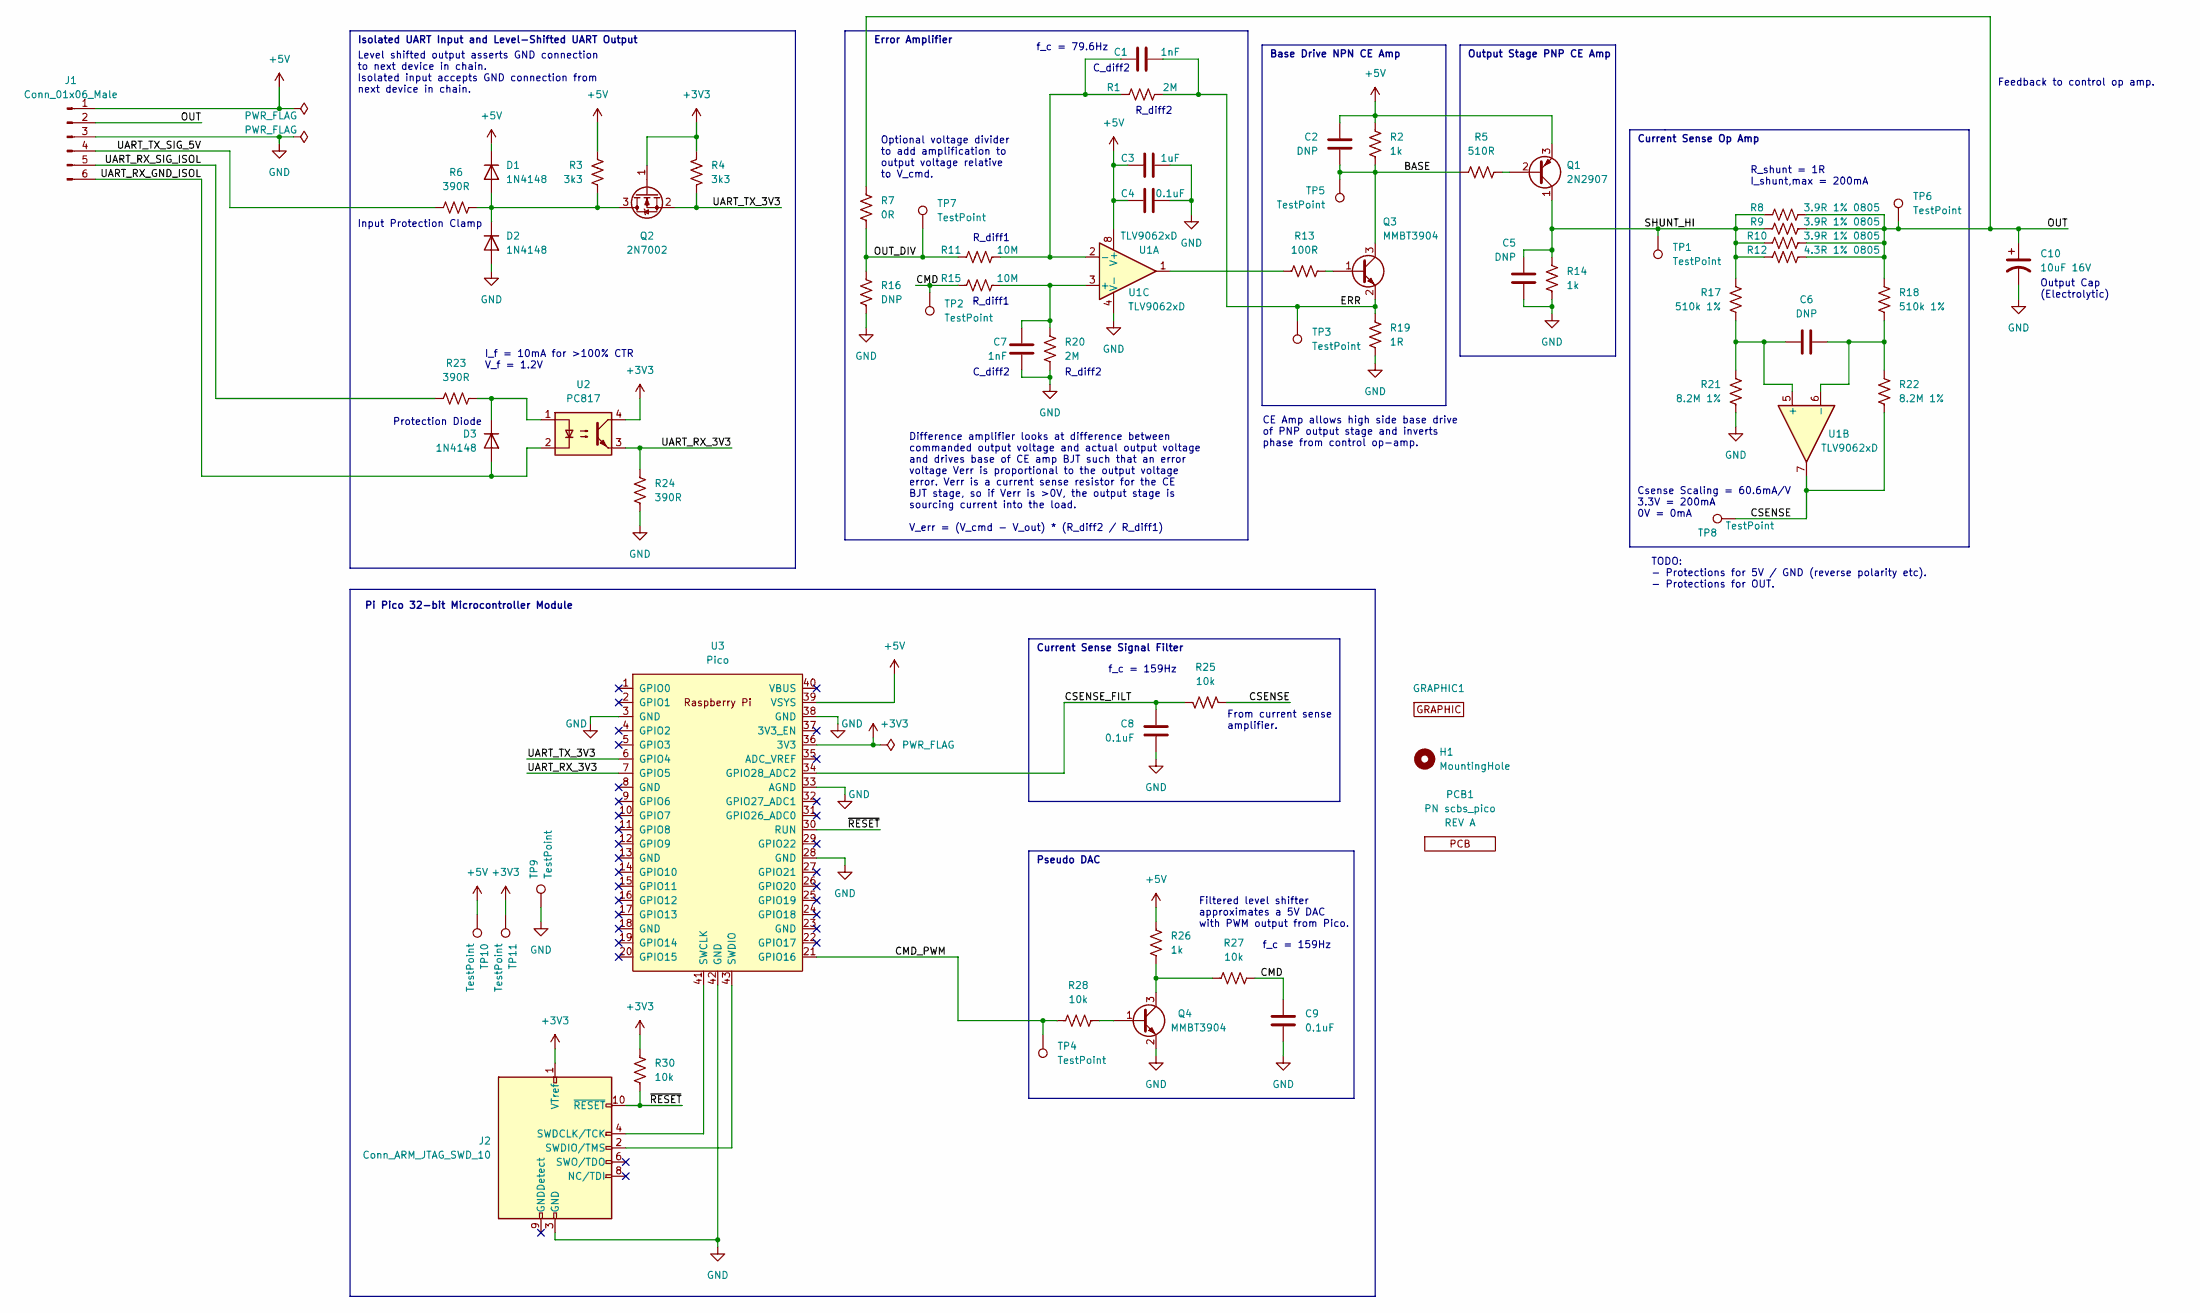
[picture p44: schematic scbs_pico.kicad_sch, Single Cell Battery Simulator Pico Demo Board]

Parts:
C1, C7: 1nF; C_0805_2012Metric
C2, C5, C6: DNP; C_0805_2012Metric
C3: 1uF; C_0805_2012Metric
C4, C8, C9: 0.1uF; C_0805_2012Metric
C10: 10uF 16V
D1, D2, D3: 1N4148; D_SOD-123; MPN 1N4148W-TP
GRAPHIC1: Graphic; bird_with_pants_small_flipped; MPN DNP
H1: MountingHole; MountingHole_3.2mm_M3; MPN DNP
J1: Conn_01x06_Male; PinHeader_1x06_P2.54mm_Horizontal; MPN PREC006SBAN-M71RC
J2: Conn_ARM_JTAG_SWD_10; PinHeader_2x05_P1.27mm_Vertical_SMD; MPN 4048
PCB1: PCB; PCB_PN_REV_small; MPN PN scbs_pico
Q1: 2N2907; TO-92; MPN PN2907ATF
Q2: 2N7002; SOT-23; MPN 2N7002
Q3, Q4: MMBT3904; SOT-23
R1, R20: 2M; R_0805_2012Metric
R2, R14, R26: 1k; R_0805_2012Metric
R3, R4: 3k3; R_0805_2012Metric
R5: 510R; R_0805_2012Metric
R6, R23, R24: 390R; R_0805_2012Metric
R7: 0R; R_0805_2012Metric
R8, R9, R10: 3.9R 1% 0805; R_0805_2012Metric
R11, R15: 10M; R_0805_2012Metric
R12: 4.3R 1% 0805; R_0805_2012Metric
R13: 100R; R_0805_2012Metric
R16: DNP; R_0805_2012Metric
R17, R18: 510k 1%; R_0805_2012Metric
R19: 1R; R_0805_2012Metric
R21, R22: 8.2M 1%; R_0805_2012Metric
R25, R27, R28, R30: 10k; R_0805_2012Metric
TP1, TP2, TP3, TP4, TP5, TP6, TP7, TP8, TP9, TP10, TP11: TestPoint; TestPoint_Pad_2.0x2.0mm
U1: TLV9062xD; SOIC-8_3.9x4.9mm_P1.27mm; MPN TLV9062IDR
U2: PC817; DIP-4_W7.62mm; MPN BPC-817S ( C BIN )
U3: Pico; RPi_Pico_SMD_TH; MPN SC0915

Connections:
+3V3: J2.1 (VTref), Q2.1 (G), R4.1, R30.1, TP11.1, U2.4, U3.36 (3V3)
+5V: C2.1, C3.1, C4.1, D1.1 (K), J1.1, Q1.3 (E), R2.1, R3.1, R26.1, TP10.1, U1.8 (V+), U3.39 (VSYS)
/BASE: C2.2, Q3.3 (C), R2.2, R5.1, TP5.1
/CMD: C9.1, R15.1, R27.2, TP2.1
/CMD_PWM: R28.1, TP4.1, U3.21 (GPIO16)
/CSENSE: R22.2, R25.1, TP8.1, U1.7
/CSENSE_FILT: C8.1, R25.2, U3.34 (GPIO28_ADC2)
/ERR: C1.2, Q3.2 (E), R1.2, R19.1, TP3.1
/OUT: C10.1, J1.2, R7.1, R8.2, R9.2, R10.2, R12.2, R18.1, TP6.1
/OUT_DIV: R7.2, R11.1, R16.1, TP7.1
/SHUNT_HI: C5.1, Q1.1 (C), R8.1, R9.1, R10.1, R12.1, R14.1, R17.1, TP1.1
/UART_RX_3V3: R24.1, U2.3, U3.7 (GPIO5)
/UART_RX_GND_ISOL: D3.2 (A), J1.6, U2.2
/UART_RX_SIG_ISOL: J1.5, R23.1
/UART_TX_3V3: Q2.2 (S), R4.2, U3.6 (GPIO4)
/UART_TX_SIG_5V: J1.4, R6.1
/~RESET: J2.10 (~RESET), R30.2, U3.30 (RUN)
GND: C3.2, C4.2, C5.2, C7.2, C8.2, C9.2, C10.2, D2.2 (A), J1.3, J2.3 (GND), J2.5 (GND), Q4.2 (E), R14.2, R16.2, R19.2, R20.2, R21.2, R24.2, TP9.1, U1.4 (V-), U3.3 (GND), U3.28 (GND), U3.33 (AGND), U3.38 (GND), U3.42 (GND)
unnamed: C1.1, R1.1, R11.2, U1.2 (-)
unnamed: C6.1, R17.2, R21.1, U1.5 (+)
unnamed: C6.2, R18.2, R22.1, U1.6 (-)
unnamed: C7.1, R15.2, R20.1, U1.3 (+)
unnamed: D1.2 (A), D2.1 (K), Q2.3 (D), R3.2, R6.2
unnamed: D3.1 (K), R23.2, U2.1
unnamed: J2.2 (SWDIO/TMS), U3.43 (SWDIO)
unnamed: J2.4 (SWDCLK/TCK), U3.41 (SWCLK)
unnamed: Q1.2 (B), R5.2
unnamed: Q3.1 (B), R13.2
unnamed: Q4.1 (B), R28.2
unnamed: Q4.3 (C), R26.2, R27.1
unnamed: R13.1, U1.1

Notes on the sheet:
R_diff1
Input Protection Clamp
Difference amplifier looks at difference between commanded output voltage and actual output voltage and drives base of CE amp BJT such that an error voltage Verr is proportional to the output voltage error. Verr is a current sense resistor for the CE BJT stage, so if Verr is >0V, the output stage i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
Protection Diode
Error Amplifier
Pseudo DAC
f_c = 79.6Hz
f_c = 159Hz
Csense Scaling = 60.6mA/V 3.3V = 200mA 0V = 0mA
Current Sense Op Amp
C_diff2
Feedback to control op amp.
Isolated UART Input and Level-Shifted UART Output
Pi Pico 32-bit Microcontroller Module
Optional voltage divider to add amplification to output voltage relative to V_cmd.
Output Stage PNP CE Amp
R_diff2
From current sense amplifier.
CE Amp allows high side base drive of PNP output stage and inverts phase from control op-amp.
Filtered level shifter approximates a 5V DAC with PWM output from Pico.
TODO: - Protections for 5V / GND (reverse polarity etc). - Protections for OUT.
Base Drive NPN CE Amp
R_shunt = 1R I_shunt,max = 200mA
Output Cap (Electrolytic)
I_f = 10mA for >100% CTR V_f = 1.2V
Current Sense Signal Filter
Level shifted output asserts GND connection to next device in chain. Isolated input accepts GND connection from next device in chain.

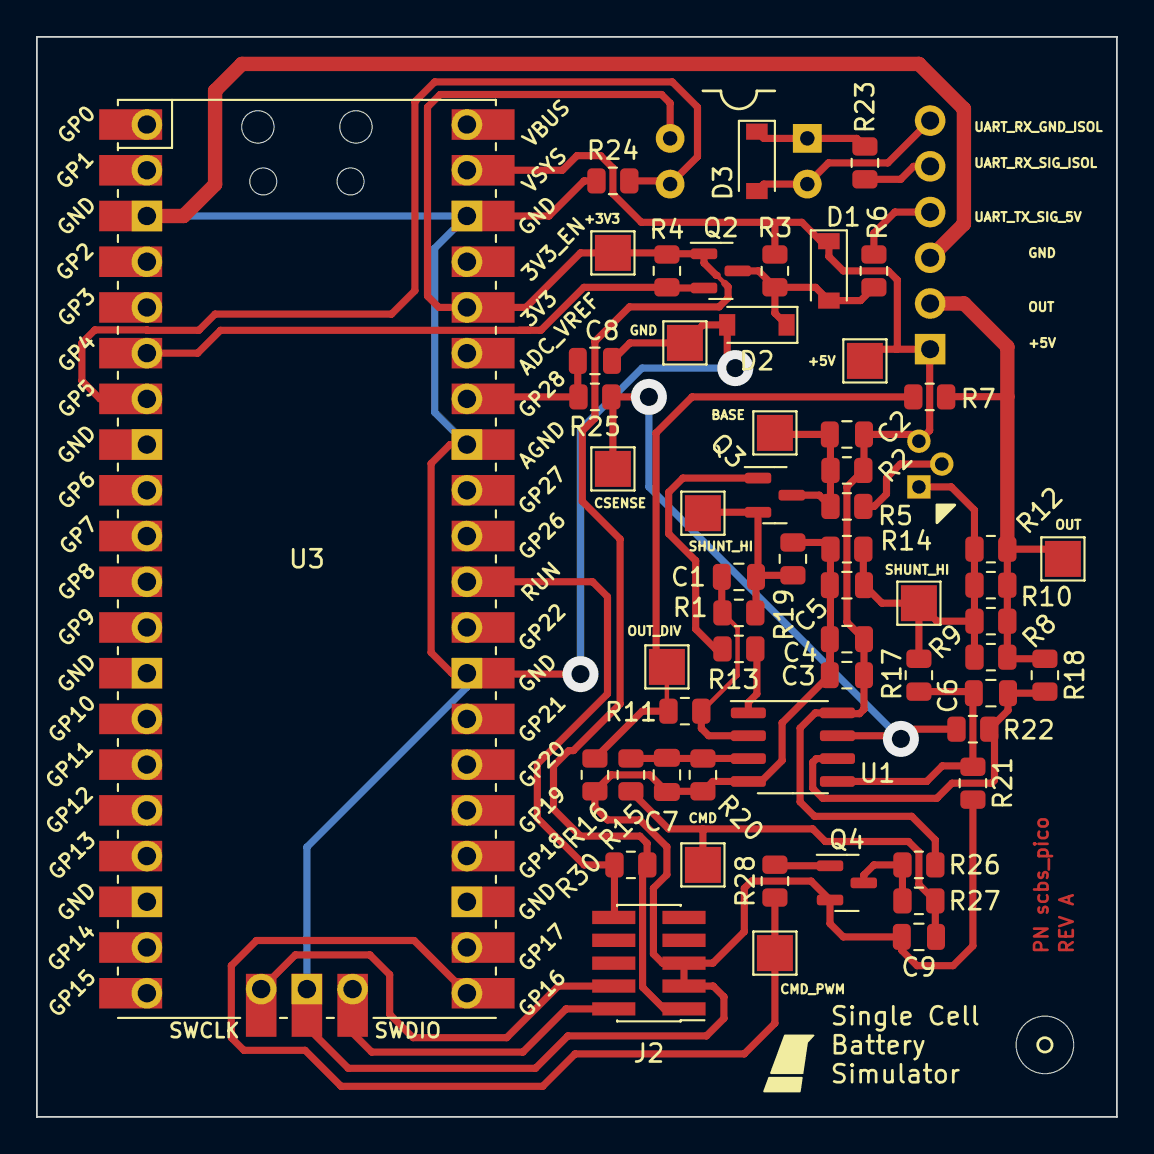
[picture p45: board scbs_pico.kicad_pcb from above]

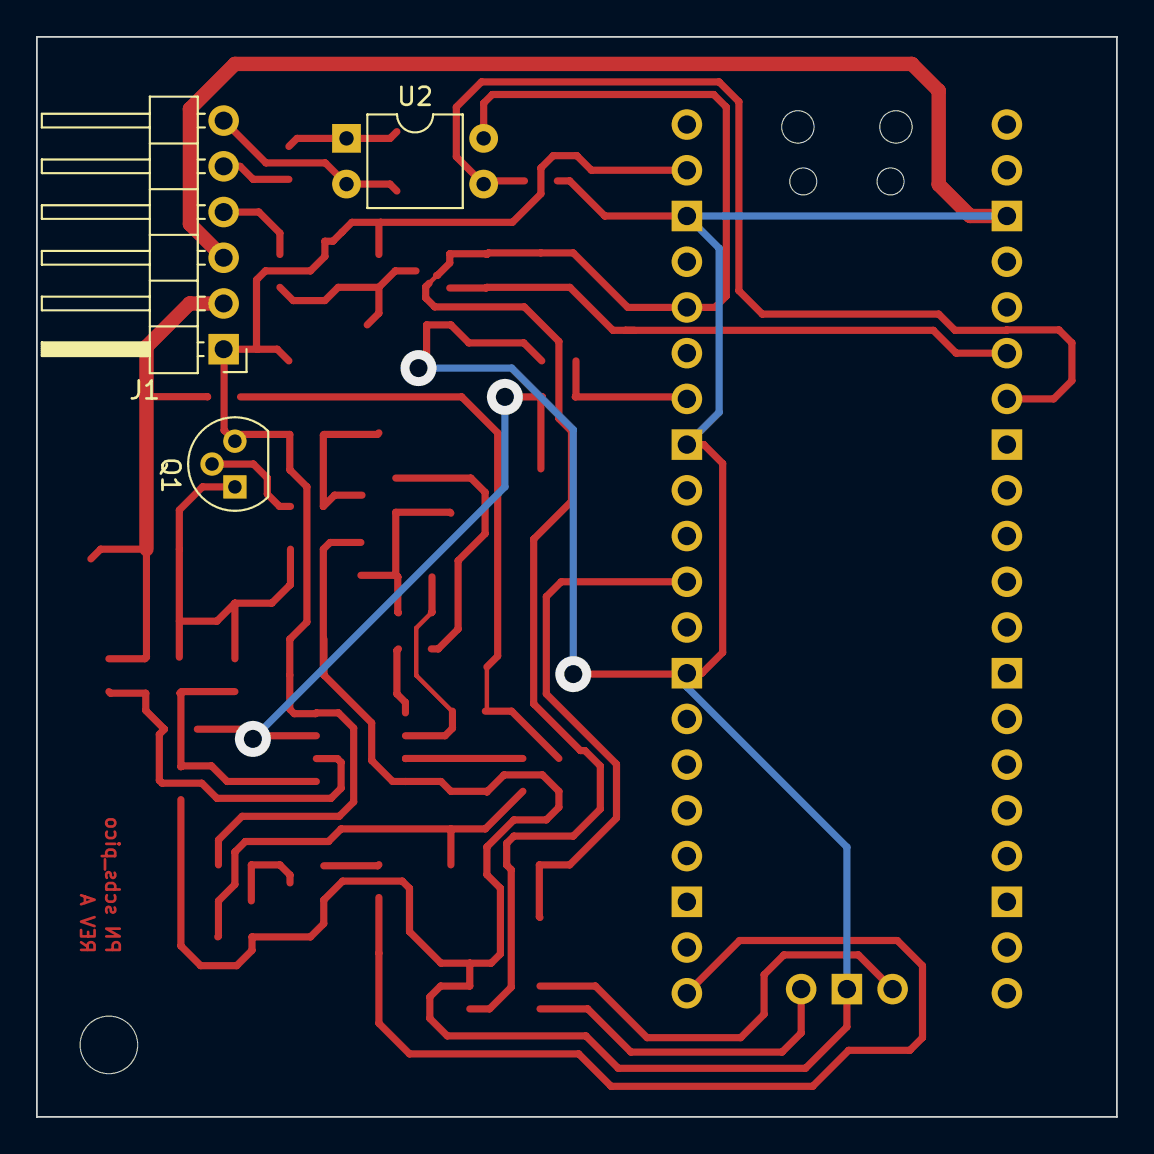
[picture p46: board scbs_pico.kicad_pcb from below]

Board: 2 copper layers, 60.0 x 60.0 mm, 64 parts (3 on the bottom side), 31 nets.

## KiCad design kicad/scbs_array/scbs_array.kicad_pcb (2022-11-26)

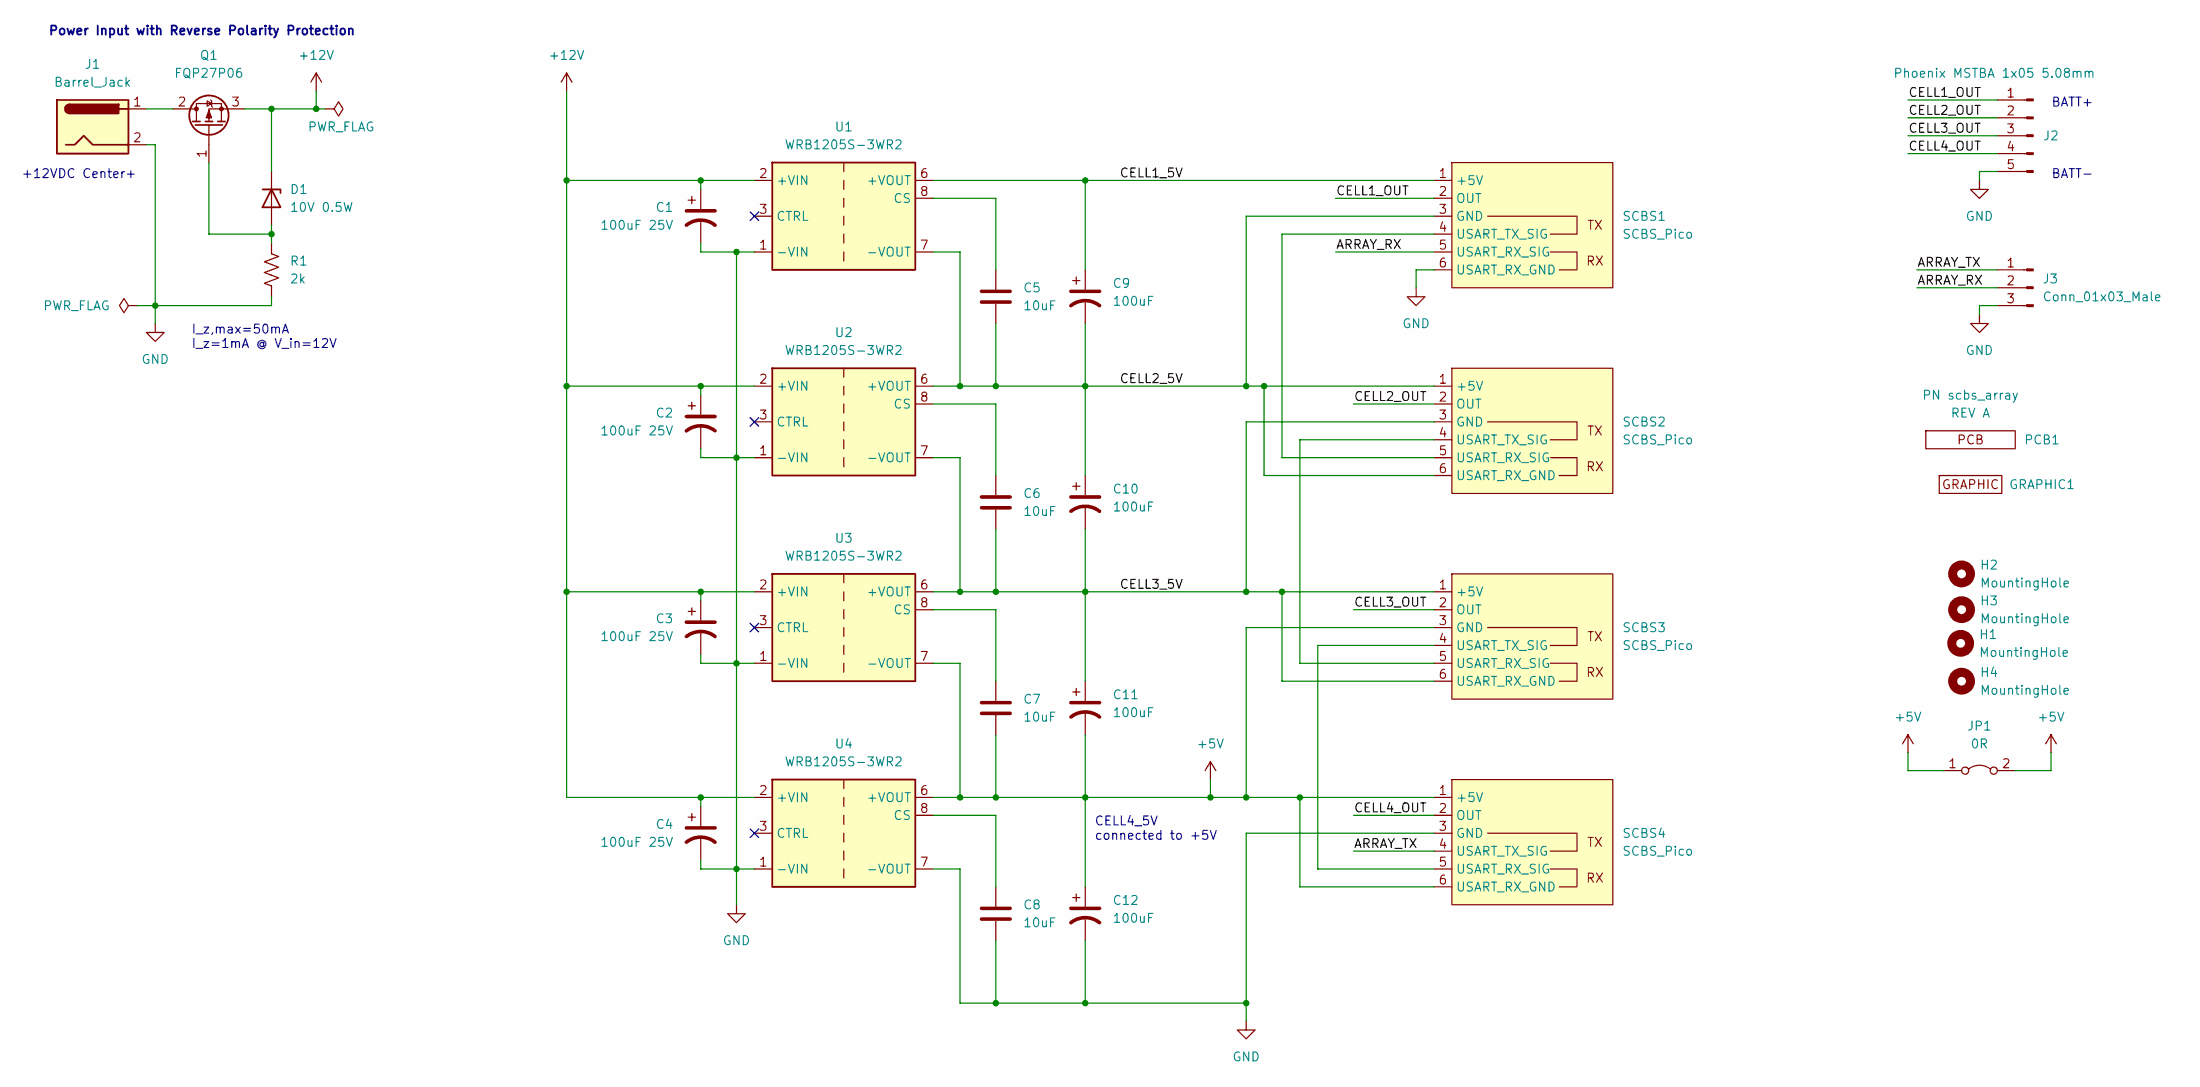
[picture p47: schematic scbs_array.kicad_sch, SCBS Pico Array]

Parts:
C1, C2, C3, C4: 100uF 25V; CP_Radial_D5.0mm_P2.50mm
C5, C6, C7, C8: 10uF; C_0805_2012Metric
C9, C10, C11, C12: 100uF; CP_Radial_D5.0mm_P2.50mm
D1: 10V 0.5W; D_MELF
GRAPHIC1: Graphic; bird_with_pants_small_flipped
H1, H2, H3, H4: MountingHole; MountingHole_3.2mm_M3
J1: Barrel_Jack; SOFNG_DC005-T20; MPN DC005-T20
J2: Phoenix MSTBA 1x05 5.08mm; PhoenixContact_MSTBA_2,5_5-G-5,08_1x05_P5.08mm_Horizontal
J3: Conn_01x03_Male; PinHeader_1x03_P2.54mm_Horizontal
JP1: 0R; R_0805_2012Metric
PCB1: PCB; PCB_PN_REV; MPN PN scbs_array
Q1: FQP27P06; TO-220-3_Horizontal_TabDown; MPN FQP27P06
R1: 2k; R_0805_2012Metric
SCBS1, SCBS2, SCBS3, SCBS4: SCBS_Pico
U1, U2, U3, U4: WRB1205S-3WR2; Converter_DCDC_TRACO_TMR-xxxx_THT

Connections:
+5V: C7.2, C11.2, C12.1, JP1.1 (A), JP1.2 (B), SCBS3.3 (GND), SCBS4.1 (+5V), SCBS4.6 (USART_RX_GND), U3.7 (-VOUT), U4.6 (+VOUT)
+12V: C1.1, C2.1, C3.1, C4.1, D1.1 (K), Q1.3 (S), U1.2 (+VIN), U2.2 (+VIN), U3.2 (+VIN), U4.2 (+VIN)
/ARRAY_RX: J3.2, SCBS1.5 (USART_RX_SIG)
/ARRAY_TX: J3.1, SCBS4.4 (USART_TX_SIG)
/CELL1_5V: C9.1, SCBS1.1 (+5V), U1.6 (+VOUT)
/CELL1_OUT: J2.1, SCBS1.2 (OUT)
/CELL2_5V: C5.2, C9.2, C10.1, SCBS1.3 (GND), SCBS2.1 (+5V), SCBS2.6 (USART_RX_GND), U1.7 (-VOUT), U2.6 (+VOUT)
/CELL2_OUT: J2.2, SCBS2.2 (OUT)
/CELL3_5V: C6.2, C10.2, C11.1, SCBS2.3 (GND), SCBS3.1 (+5V), SCBS3.6 (USART_RX_GND), U2.7 (-VOUT), U3.6 (+VOUT)
/CELL3_OUT: J2.3, SCBS3.2 (OUT)
/CELL4_OUT: J2.4, SCBS4.2 (OUT)
GND: C1.2, C2.2, C3.2, C4.2, C8.2, C12.2, J1.2, J2.5, J3.3, R1.2, SCBS1.6 (USART_RX_GND), SCBS4.3 (GND), U1.1 (-VIN), U2.1 (-VIN), U3.1 (-VIN), U4.1 (-VIN), U4.7 (-VOUT)
unnamed: C5.1, U1.8 (CS)
unnamed: C6.1, U2.8 (CS)
unnamed: C7.1, U3.8 (CS)
unnamed: C8.1, U4.8 (CS)
unnamed: D1.2 (A), Q1.1 (G), R1.1
unnamed: J1.1, Q1.2 (D)
unnamed: SCBS1.4 (USART_TX_SIG), SCBS2.5 (USART_RX_SIG)
unnamed: SCBS2.4 (USART_TX_SIG), SCBS3.5 (USART_RX_SIG)
unnamed: SCBS3.4 (USART_TX_SIG), SCBS4.5 (USART_RX_SIG)

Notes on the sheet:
+12VDC Center+
CELL4_5V connected to +5V
I_z,max=50mA I_z=1mA @ V_in=12V
Power Input with Reverse Polarity Protection
BATT-
BATT+

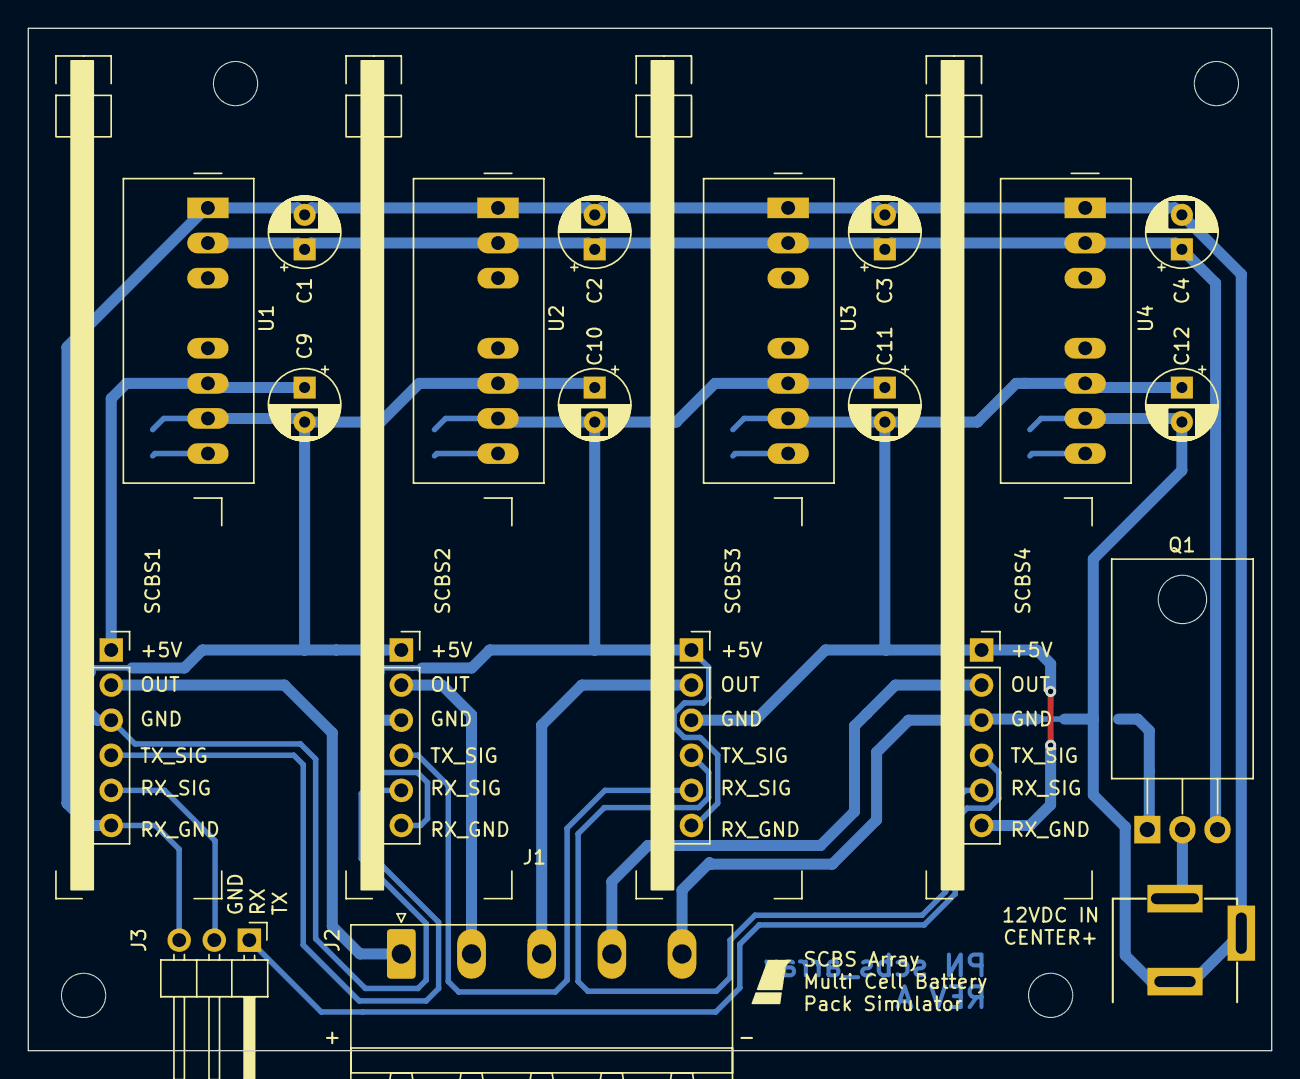
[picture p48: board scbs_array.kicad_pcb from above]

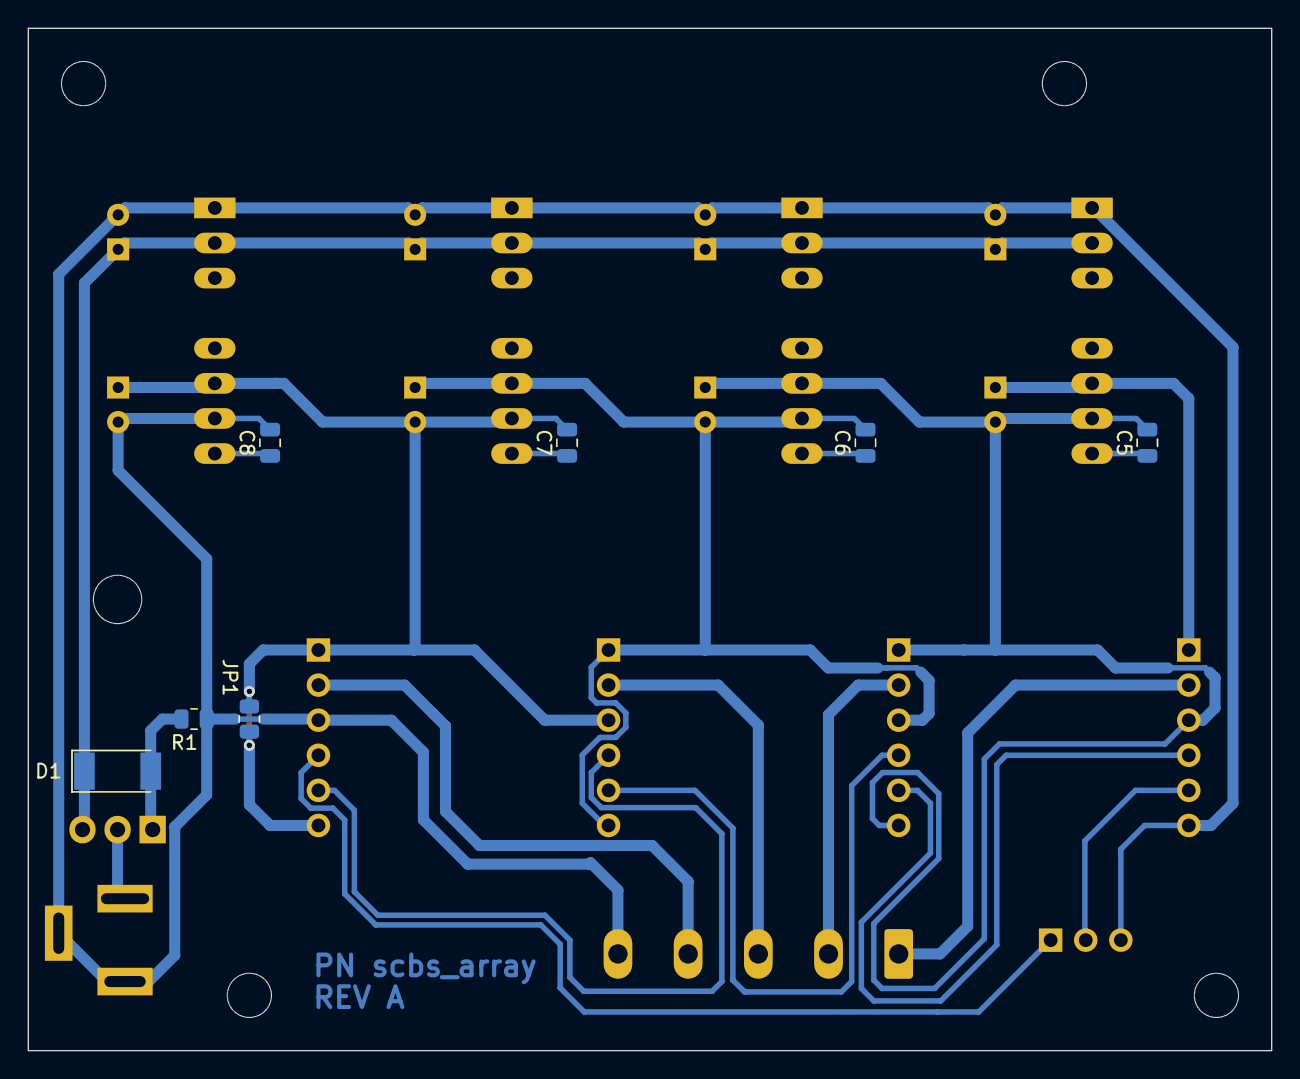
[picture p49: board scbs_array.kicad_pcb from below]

Board: 2 copper layers, 90.0 x 74.0 mm, 33 parts (8 on the bottom side), 21 nets.

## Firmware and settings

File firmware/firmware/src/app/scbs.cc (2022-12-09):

#include "scbs.hh"
#include <stdio.h> // for printing
#include <stdlib.h> // for strtof

const uint16_t kMaxPWMCount = 1000; // Clock is 125MHz, shoot for 125kHz PWM.
const uint16_t kPWMDefaultDuty = 0; // out of kMaxPWMCount.
const float kPowerSupplyVoltage5V = 5.0f; // [V]
const float kMaxOutputVoltage = 4.5f; // [V]
const float kMinOutputVoltage = 0.0f; // [V]

const float kOutputVoltageCalCoeffX3 = -0.006624709f;
const float kOutputVoltageCalCoeffX2 = 0.07218648f;
const float kOutputVoltageCalCoeffX = -0.278278555f;
const float kOutputVoltageCalCoeffConst = 0.079586014f;

const uint32_t kPacketReceivedBlinkTimeMs = 10;
const uint32_t kRegisterWriteBlinkTimeMs = 500;
const uint32_t kRegisterReadBlinkTimeMs = 100;

// const float kPowerSupplyVoltage3V3 = 3.3f;
const uint16_t kMaxADCCount = 1<<12;
// const float kADCConversionFactor = kPowerSupplyVoltage3V3 / kMaxADCCount;
const float kMaxCsenseCurrent = 200.0f;

/** Public Functions **/

/**
 * @brief Constructor, copies configuration into the new SCBS object.
*/
SCBS::SCBS(SCBSConfig_t config) {
    config_ = config;
}

/**
 * @brief Init function, should be called only once when peripherals are being initialized.
*/
void SCBS::Init() {
    // Set up status LED.
    gpio_init(config_.led_pin);
    gpio_set_dir(config_.led_pin, GPIO_OUT);

    // Set up comms UART.
    uart_init(config_.uart_id, config_.uart_baud);
    gpio_set_function(config_.uart_tx_pin, GPIO_FUNC_UART);
    gpio_set_function(config_.uart_rx_pin, GPIO_FUNC_UART);

    uart_set_hw_flow(config_.uart_id, false, false); // no CTS/RTS
    uart_set_format(config_.uart_id, config_.uart_data_bits, config_.uart_stop_bits, config_.uart_parity);
    uart_set_fifo_enabled(config_.uart_id, true);

    memset(uart_rx_buf_, '\0', kMaxUARTBufLen);
    uart_rx_buf_len_ = 0;

    // Set up PWM output for voltage control.
    gpio_set_function(config_.pwm_pin, GPIO_FUNC_PWM);
    // Figure out which slice we just connected to the LED pin
    uint slice_num = pwm_gpio_to_slice_num(config_.pwm_pin);
    pwm_set_wrap(slice_num, kMaxPWMCount);
    pwm_set_chan_level(slice_num, config_.pwm_channel, kPWMDefaultDuty);
    pwm_set_enabled(slice_num, true);

    // Set up current sense ADC input.
    adc_init();
    adc_gpio_init(config_.csense_pin);

    // give em a little blink
    gpio_put(config_.led_pin, 1);
    sleep_ms(100);
    gpio_put(config_.led_pin, 0);

    printf("SCBS::Init(): Init completed.\r\n");
}

/**
 * @brief Update function, should be called every loop.
*/
void SCBS::Update() {
    // Communication Process
    if (ReceivePacket() != 0) {
        TurnOnStatusLED(kPacketReceivedBlinkTimeMs);

        BSPacket packet = BSPacket(uart_rx_buf_);
        if (packet.IsValid()) {
            printf("SCBS::Update(): Packet is valid!\r\n");
            switch(packet.GetPacketType()) {
                case BSPacket::DIS:
                    DISPacketHandler(DISPacket(uart_rx_buf_));
                    break;
                case BSPacket::MRD:
                    MRDPacketHandler(MRDPacket(uart_rx_buf_));
                    break;
                case BSPacket::MWR:
                    MWRPacketHandler(MWRPacket(uart_rx_buf_));
                    break;
                case BSPacket::SRD:
                    SRDPacketHandler(SRDPacket(uart_rx_buf_));
                    break;
                case BSPacket::SWR:
                    SWRPacketHandler(SWRPacket(uart_rx_buf_));
                    break;
                case BSPacket::SRS:
                    SRSPacketHandler(SRSPacket(uart_rx_buf_));
                    break;
                default:
                    printf("SCBS::Update():     Unrecognized packet type.\r\n");
            }
        } else {
            printf("SCBS::Update(): Packet is invalid.\r\n");
        }
        FlushUARTBuf();
    }
    
    // GPIO Process
    SetOutputVoltage(output_voltage_);
    ReadOutputCurrent();

    // Update status LED
    if (status_led_on_ && time_us_32() > status_led_off_timestamp_) {
        gpio_put(config_.led_pin, 0);
        status_led_on_ = false;
    }
}

/**
 * @brief Returns the ID number of the SCBS object.
*/
uint16_t SCBS::GetCellID() {
    return cell_id_;
}

/** Private Functions **/

/**
 * @brief Cell Discover packet handler. Enumerates the device and sends out a packet to the next
 * device in the chain.
 * @param[in] packet Incoming BSDIS packet.
*/
void SCBS::DISPacketHandler(DISPacket packet_in) {
    if (packet_in.IsValid()) {
        printf("SCBS::DISPacketHandler: Formed a valid DIS packet!\r\n");
        cell_id_ = packet_in.last_cell_id + 1;
        DISPacket packet_out = DISPacket(cell_id_);
        TransmitPacket(packet_out);
    } else {
        printf("SCBS::DISPacketHandler: Formed a DIS packet but it wasn't valid!\r\n");
        TransmitError(kErrCodeReceivedInvalidPacket);
    }
}

/**
 * @brief Handler for an MWR (Multipl WRite) packet. Performs a register write and forwards the packet to the next device,
 * or returns an SRS packet with an error code if something went wrong.
 * @retval packet_in Incoming MWR packet.
*/
void SCBS::MWRPacketHandler(MWRPacket packet_in) {
    if (packet_in.IsValid()) {
        printf("SCBS::MWRPacketHandler: Formed a valid MWR packet!\r\n");

        uint16_t err_code = WriteRegister(packet_in.reg_addr, packet_in.value);
        if (err_code != kErrCodeNone) {
            printf("SCBS::MWRPacketHandler: Register write to address 0x%X failed with code 0x%X.\r\n", packet_in.reg_addr, err_code);
            TransmitError(err_code);
            return; // drop original packet
        } else {
            // Pass to next device in the chain.
            TransmitPacket(packet_in);
        }
    } else {
        printf("SCBS::MWRPacketHandler: Formed an MWR packet but it wasn't valid!\r\n");
        TransmitError(kErrCodeReceivedInvalidPacket);
    }
}
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

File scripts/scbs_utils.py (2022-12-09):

import argparse
from ast import literal_eval
import serial

parser = argparse.ArgumentParser(description="SCBS master utility.")
parser.add_argument("serial_port", type=str, help="Serial port to use (e.g. 'COM3').")
# parser.add_argument("command", type="str", help=
# """
# Command to run. Options include:
# DIS - Cell Discover
# MRD - Multi Read
# MWR - Multi Write
# SRD - Single Read*
# SWR - Single Write*
# SRS - Single Response*
# """)
args = parser.parse_args()

MAX_REG_ADDR = 0x9999

def validate_address(address_str):
    address = literal_eval(address_str)
    if (address > MAX_REG_ADDR or address < 0):
        raise Exception("Address {:x} is out of range.".format(address))

def calculate_checksum(contents_str):
    """
    @brief Calculates XOR checksum of a string.
    @param[in] contents_str String including header and contents (what would go between $ and *).
    @retval Checksum (integer).
    """
    checksum = 0
    for i in range(len(contents_str)):
        checksum ^= ord(contents_str[i]) # XOR with character's ASCII value
    
    return checksum

def packetize(contents_str):
    """
    @brief Adds $ and * token, as well as checksum.
    @param[in] contents_str String including header and contents (what would go between $ and *).
    @retval Complete packet string.
    """
    return "${}*{:x}\r\n".format(contents_str, calculate_checksum(contents_str))

def transmit(port, packet):
    print("\tSending: {}".format(packet), end="")
    port.write(bytes(packet, 'utf-8'))
    port.flush()


# def transmit()

def send_dis():
    args_str = input("Enter ID of first cell:")
    print()

def main():
    print(
"""Welcome to the SCBS Master Utility!
Supported Commands:
    DIS - Cell Discover
        DIS <PREV_CELL_ID>
    MRD - Multi Read
        MRD <REG_ADDR>
    MWR - Multi Write
        MWR <REG_ADDR> <VALUE>
    SRD - Single Read
        SRD <CELL_ID> <REG_ADDR>
    SWR - Single Write
        SWR <CELL_ID> <REG_ADDR> <VALUE>
    SRS - Single Response
        SRS <CELL_ID> <VALUE>
Type EXIT to quit."""
    )
    ser = serial.Serial(args.serial_port,
        baudrate=9600,
        bytesize=8,
        parity='N',
        stopbits=1,
        timeout=5 #[sec]
    )
    ser.close()
    ser.open()
    while(True):
        command = input(">>> ")
        command_words = command.split(" ")
        num_args = len(command_words)
        if command_words[0].lower() == "exit":
            return
        elif command_words[0] == "DIS":
            if (num_args != 2):
                print("Invalid number of arguments for BSDIS! Excpected 1 but got {}.".format(num_args))
                continue
            transmit(ser, packetize("BSDIS,{}".format(command_words[1])))
            print("\tResponse: {}".format(ser.readline()))
        elif command_words[0] == "MRD":
            if (num_args != 2):
                print("Invalid number of arguments for BSDIS! Excpected 1 but got {}.".format(num_args))
                continue
            transmit(ser, packetize("BSMRD,{}".format(command_words[1])))
            print("\tRespons: {}".format(ser.readline()))
        elif command_words[0] == "MWR":
            if (num_args != 3):
                print("Invalid number of arguments for BSDIS! Excpected 2 but got {}.".format(num_args))
                continue
            transmit(ser, packetize("BSMWR,{},{}".format(command_words[1], command_words[2])))
            print("\tResponse: {}".format(ser.readline()))
        elif command_words[0] == "SRD":
            if (num_args != 3):
                print("Invalid number of arguments for BSSRD! Expected 3 but got {}.".format(num_args))
                continue
            transmit(ser, packetize("BSSRD,{},{}".format(command_words[1], command_words[2])))
            print("\tResponse: {}".format(ser.readline()))
        elif command_words[0] == "SWR":
            if (num_args != 4):
                print("Invalid number of arguments for BSSRD! Expected 4 but got {}.".format(num_args))
                continue
            transmit(ser, packetize("BSSWR,{},{},{}".format(command_words[1], command_words[2], command_words[3])))
            print("\tResponse: {}".format(ser.readline()))
        elif command_words[0] == "SRS":
            if (num_args != 3):
                print("Invalid number of arguments for BSSRS! Expected 3 but got {}.".format(num_args))
                continue
            transmit(ser, packetize("BSSRS,{},{}".format(command_words[1], command_words[2])))
            print("\tResponse: {}".format(ser.readline()))
        else:
            print("Unrecognized argument.")
            
    
    ser.close()
    # print(calculate_checksum("BSDIS,0"))

if __name__ == "__main__":
    main()

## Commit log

2022-11-06 Demo board v0.1
    [design_calcs.xlsx, scbs_demo.kicad_pcb, scbs_demo.kicad_sch]
2022-11-08 scbs_pico hardware Rev A, initial firmware
    [scbs_demo.kicad_pcb, scbs_demo.kicad_sch]
2022-11-12 Working SCBS multi-read packets on device
    [scbs_pico.csv, scbs_pico.kicad_pcb, scbs_pico.kicad_sch]
2022-11-15 Add calibrated output voltage setting
    * Python script serial utility for sending DIS, MWR, MRD commands to
    device.
    * Three-coefficient polynomial calibration implemented in firmware for
    closer matching of output voltage (looks pretty darn good)! Makes up
    for the crappiness / non-linearity of the PWM pseudo-DAC driving a
    load without a buffer.
    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
    [design_calcs.xlsx, scbs_pico.kicad_sch, scbs_pico.xlsx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]
2022-11-25 Add SCBS array PCBA Rev A
    * Update design notebook.
    * Export some stuff for SCBS Pico.
    * Create SCBS Array motherboard.
    [scbs_array.kicad_pcb, scbs_array.kicad_sch, scbs_pico.kicad_pcb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]
2022-11-26 Make enclosure CAD
    [2022_06_08_09_32_02_0611.SLDPRT, 2022_06_08_09_32_02_0615.SLDPRT, 2022_06_08_09_32_02_0619.SLDPRT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]
2022-12-04 SCBS Array design, add single cell packets
    [enclosure_back_shell.STL, enclosure_front_panel.STL, enclosure_parts.3mf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]
2022-12-09 Add CELLSIM 4S documentation
    [design_calcs.xlsx, scbs_array.kicad_sch]
